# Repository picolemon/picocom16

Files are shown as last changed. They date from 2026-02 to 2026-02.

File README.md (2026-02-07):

# Picocom16
A DIY breadboard computer based on four RP2350 micro controllers that can be built without any soldering.

Markdown Logo

## Features
Easy build with no soldering.

Fast debugging using VSCode and a usb cable.

Double buffered frame buffer with simple gpu for drawing.

Async DMA bus distributes graphics and sound to each core.

Written in C with a clear and simple api.

## Display

Frame buffer: 320×224, 16 bit color palette, 60 Hz.    

GPU Method: Command dispatch and Tiling.

Blend modes:  4bit alpha composite, Additive blending.

## Memory

System RAM: 512 KB SRAM

VRAM: 512 KB SRAM

FB: 512 KB SRAM

Audio RAM: 512 KB SRAM

## DMA
VDP1 Bus - System to VDP gpu command stream async.

VDP2 Bus - VDP1 to VDP2 tile stream.

APU Bus - System to APU audio commands, audio streams, HID inputs and SD Card IO.

## Storage
Physics format: Format: SD memory card.

File System: Fat32.

## Audio
DSP mixer: play, pause, pan & frequency.

Audio formats: Raw PCM 16, OGG vorbis.

Streaming: Audio stream buffer for seamless audio looping and streaming from System core.

Rate: 11 Khz.

Output: Stereo output via 3mm jack.

Channels: 32 channels ( sfx or ogg in any combination ).

## Cores
APU - Dedicated audio processor. [ [src](sw/apu) ] [ [uf2](firmware/apu.uf2) ]

System - Game processor for game logic, building graphics and audio commands.  [ [demos](sw/demos) ] 

VDP1 - Graphics tile generator.  [ [src](sw/vdp1) ] [ [uf2](firmware/vdp1.uf2) ]

VDP2 - Tile compositor and DVI output.  [ [src](sw/vdp2) ] [ [uf2](firmware/vdp2.uf2) ]

## Examples

gfx_demo [ [src](sw/demos/gfx_demo) ] [ [uf2](firmware/gfx_demo.uf2) ]

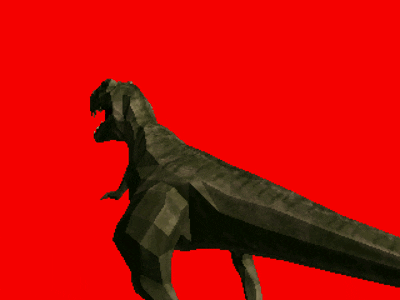
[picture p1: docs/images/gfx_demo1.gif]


input_demo  [ [src](sw/demos/gfx_demo) ] [ [uf2](firmware/gfx_demo.uf2) ]

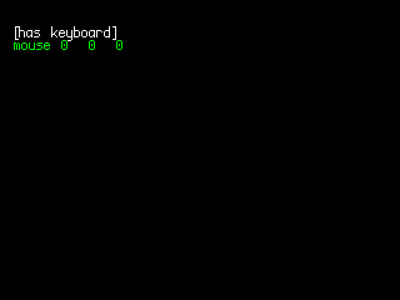
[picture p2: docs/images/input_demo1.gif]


minerload   [ [demo](https://picocom16.itch.io/minerload) ] [ [uf2](firmware/minerload.uf2) ]



## Components BOM

All components can be source from amazon or other suppliers.

    1 x Breadboard kit - SUNFOUNDER 5PCS Breadboards Kit Include 3PCS 830 Point 2PCS 400 Point Solderless Breadboard Compatible with Arduino Proto Shield Distribution Connecting Blocks 

    1 x Wire kit - 560 Pcs Jumper Wire Kit, 14 Lengths Assorted Preformed Breadboard Jumper Wires, Male to Male Solderless Jumper Cables with Storage Box for Prototyping, LED Strips, and Test Circuits 

    4 x Pre-Soldered Raspberry Pi Pico 2 with Header RP2350 Microcontroller Board Mini Board Kit Based on RP2350 Chip,Dual-core & Dual-architecture,Support C/C++/Python 

    1 x PCM5102 DAC Decoder Module I2S Interface GY-PCM5102 PHAT Format Player Board Digital-to-Analog Converter Voice Module for Arduino, Raspberry Pi with 3.5mm Jack Audio Cable, Dupont Cable 

    1 x AZDelivery Micro SD SPI Storage Board TF Memory Card Adapter Shield Module 5V compatible with Arduino Including E-Book! (Pack of 3) 

    1 x Adafruit DVI Breakout Board - For HDMI Source Devices 

    1 x 18pcs USB to DIP Breakout Adapter Converter Mini 5p USB/2.54 mm 4p/USB 2.0 4p/USB 3.0 Flat/Micro USB Type B/USB Type-B Square PCB Power Breakout Board Module

## Build guide
This is what the fully assembled breadboard looks like:

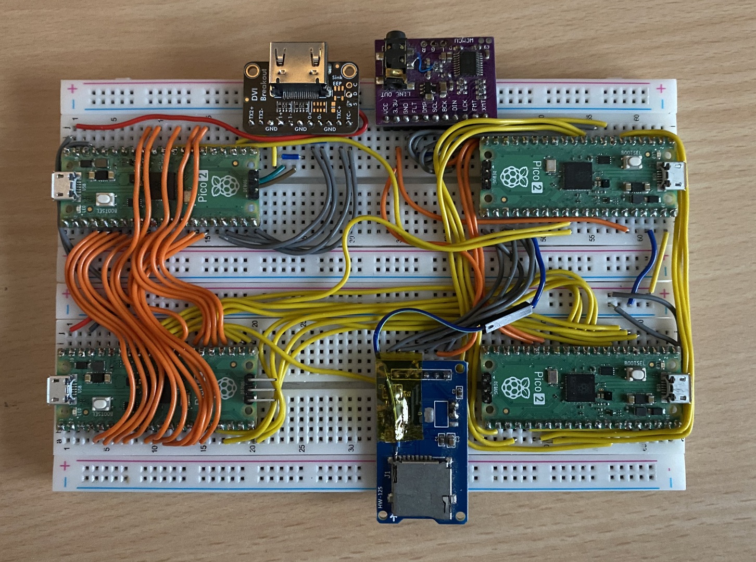
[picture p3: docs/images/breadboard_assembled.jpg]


See [docs/guides/picocom16-breadboard/Build-guide.md](docs/guides/picocom16-breadboard/Build-guide.md)

## System dependencies

VSCode: https://code.visualstudio.com/

Pico sdk: https://marketplace.visualstudio.com/items?itemName=raspberry-pi.raspberry-pi-pico

Asset tooling python deps
```
pip install bdfparser
```

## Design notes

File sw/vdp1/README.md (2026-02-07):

# VDP1
Video processor for rendering graphics

## Features
- connects to VDP2 via vdpbus 8bit wide write only bus
- sends frame and commands to VDP2 for compositing with frame buffer

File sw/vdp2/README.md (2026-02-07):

# VDP2
Background video processor and framebuffer for rendering graphics

## Features
- DVI video transmitter 
- Composites VDP1 scanlines into frame buffer
- Renders backgrounds ( and other effects ) just in time for VDP1 scanlines.
- post effects can be performed etc even using the prev frame ( currently output to dvi )

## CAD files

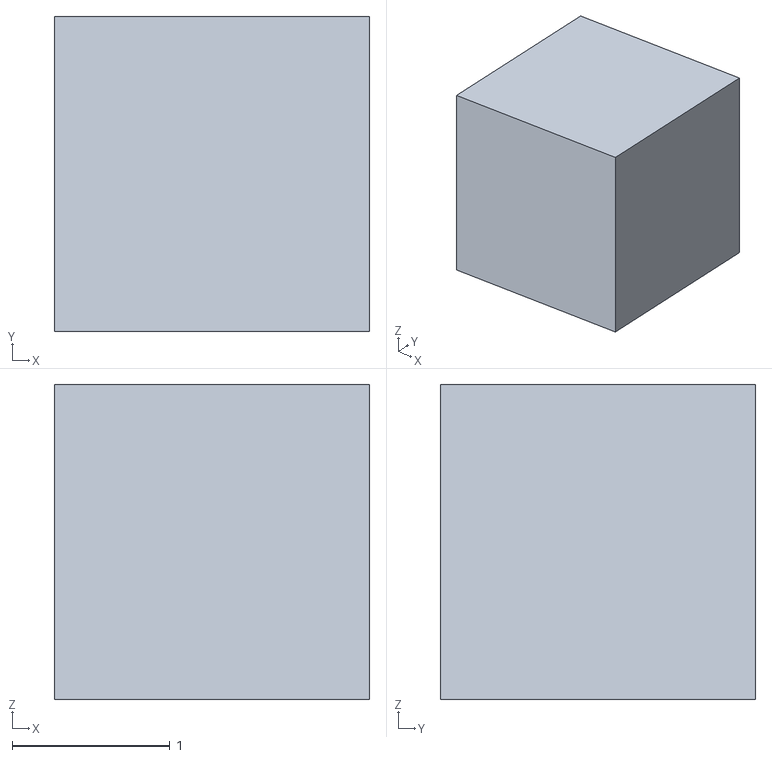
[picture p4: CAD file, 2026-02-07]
sw/demos/gfx_demo/assets/models/cube.obj
2.00 x 2.00 x 2.00

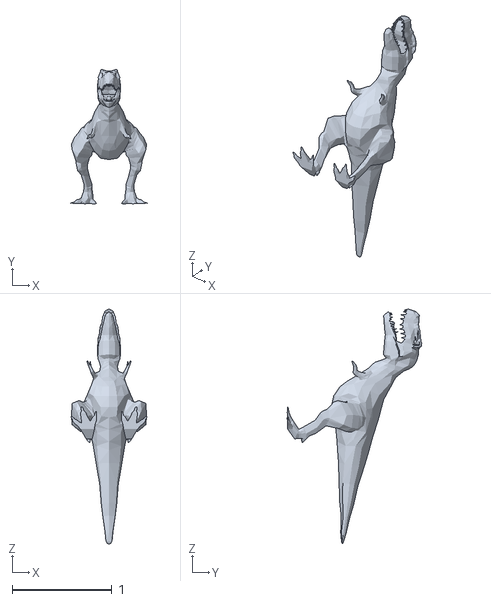
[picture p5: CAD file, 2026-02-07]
sw/demos/gfx_demo/assets/models/trex/T_Rex_1_FBX_LOW.fbx.obj
0.763 x 1.35 x 2.35

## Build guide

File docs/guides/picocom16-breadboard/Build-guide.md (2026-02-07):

# Picocom16 Breadboard build guide

## Intro
The picocom 16 breadboard console is an easy to build fully featured computer.

## BOM
    1 x Breadboard kit - SUNFOUNDER 5PCS Breadboards Kit Include 3PCS 830 Point 2PCS 400 Point Solderless Breadboard Compatible with Arduino Proto Shield Distribution Connecting Blocks 

    1 x Wire kit - 560 Pcs Jumper Wire Kit, 14 Lengths Assorted Preformed Breadboard Jumper Wires, Male to Male Solderless Jumper Cables with Storage Box for Prototyping, LED Strips, and Test Circuits 

    4 x Pre-Soldered Raspberry Pi Pico 2 with Header RP2350 Microcontroller Board Mini Board Kit Based on RP2350 Chip,Dual-core & Dual-architecture,Support C/C++/Python 

    1 x PCM5102 DAC Decoder Module I2S Interface GY-PCM5102 PHAT Format Player Board Digital-to-Analog Converter Voice Module for Arduino, Raspberry Pi with 3.5mm Jack Audio Cable, Dupont Cable 

    1 x AZDelivery Micro SD SPI Storage Board TF Memory Card Adapter Shield Module 5V compatible with Arduino Including E-Book! (Pack of 3) 

    1 x Adafruit DVI Breakout Board - For HDMI Source Devices 

    1 x 18pcs USB to DIP Breakout Adapter Converter Mini 5p USB/2.54 mm 4p/USB 2.0 4p/USB 3.0 Flat/Micro USB Type B/USB Type-B Square PCB Power Breakout Board Module

## Workflow
Copy the wiring diagrams in each section or open the Kicad project and following the wires from the schematic or pcb view.

At keys stages UF2 images are provided to test for certain features eg. does the audio output. To flash these images to specific chips plug a usb cable while holding the bootsel button then copy the image onto the RP2350 drive mount.

## Step 1 - HDMI
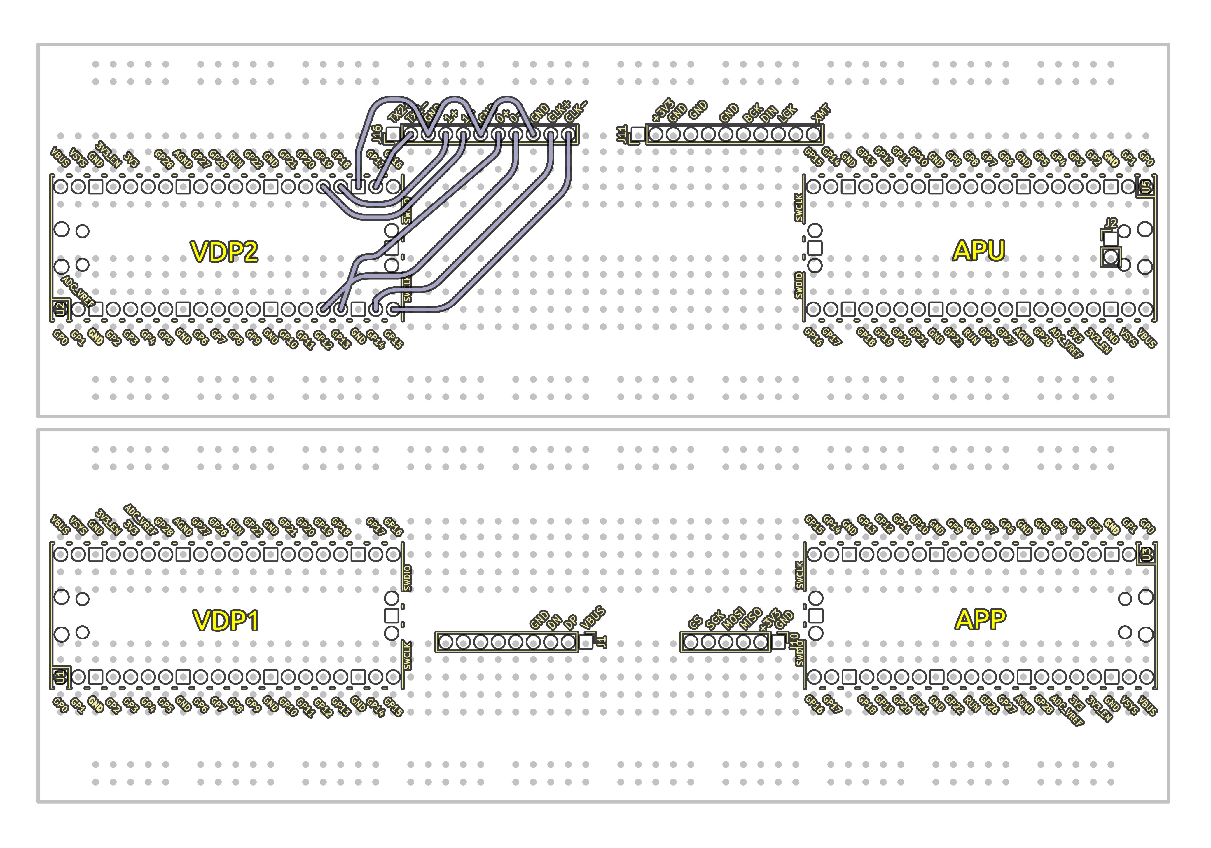
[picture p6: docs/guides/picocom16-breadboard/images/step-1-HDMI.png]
Breadboard

- Complete wiring diagram.
- Flash /firmware/vdp2.uf2 to the "VDP2" chip.
- The screen should go blue then after a few seconds a Red, Green, Blue vertical strip pattern should appear. If some colors are missing or the wrong order then double check the wiring. If no signal is detected then the display might not be compatible, some TV's require the 5V supply to be attached which requires soldering which is outside the scope of this guide.

## Step 2 - DAC
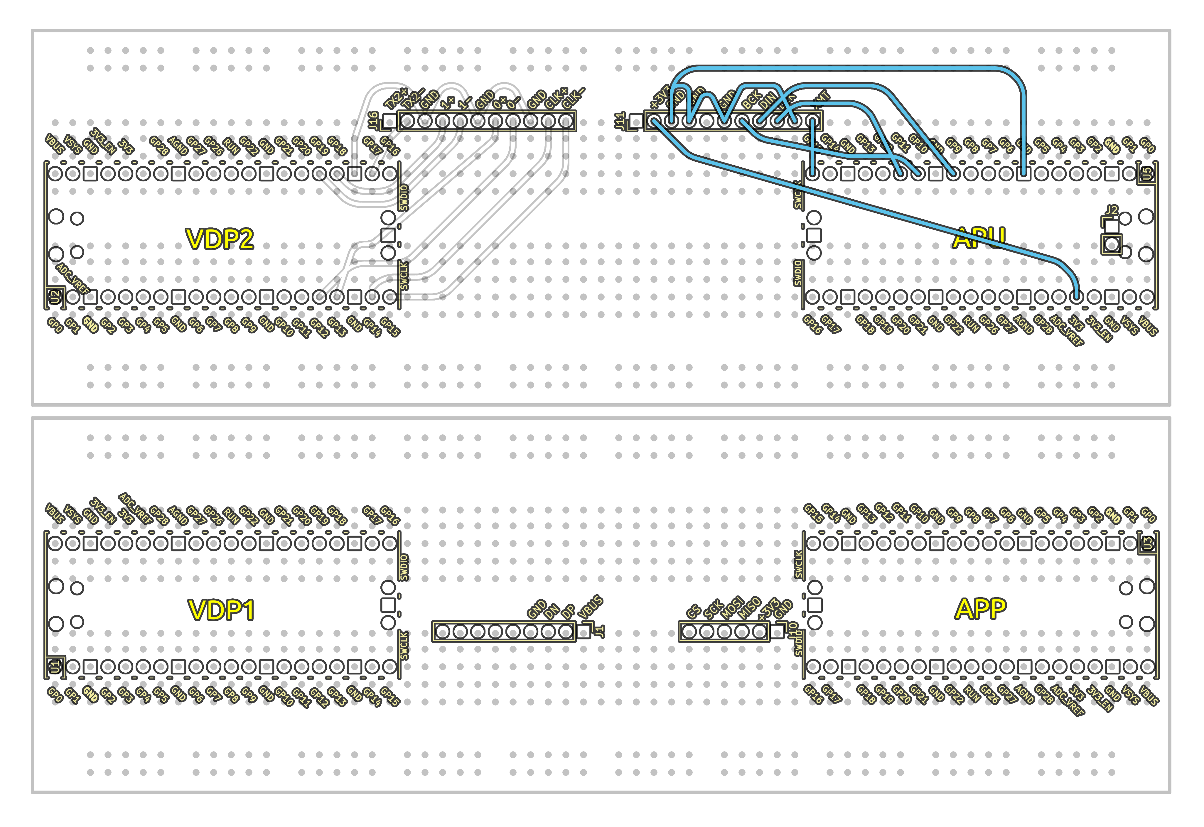
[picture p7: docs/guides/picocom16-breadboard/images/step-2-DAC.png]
Breadboard

- Follow the DAC wiring diagram. 
- Flash /firmware/vdp2.uf2 to the "APU" chip.
- Plug a set of headphones or speakers into the mini jack port on the DAC module.
- After 2 seconds a chime should be heard, if nothing plays then check the wiring.

## Step 3 - PWR
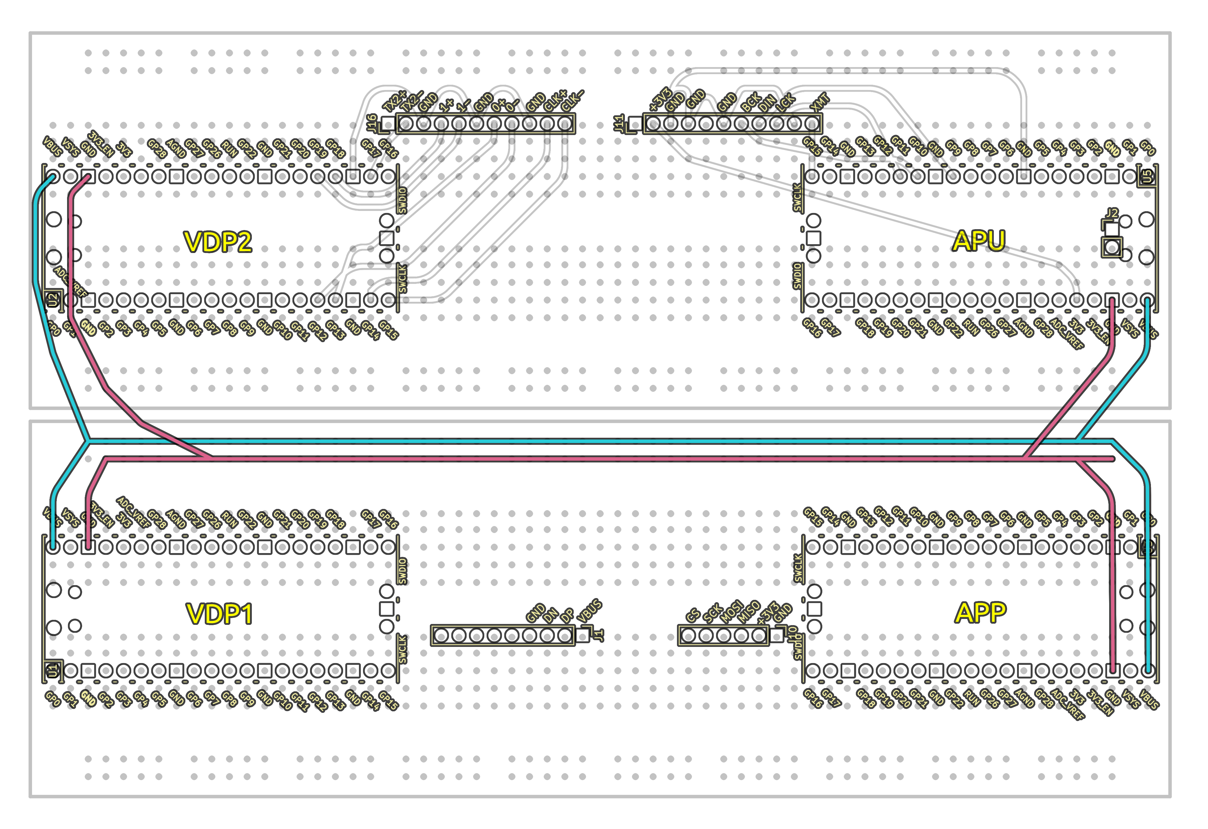
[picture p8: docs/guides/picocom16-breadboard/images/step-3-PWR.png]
Breadboard

- Follow the power wiring diagram. 

Note: Once wired, all pico the boards will startup. If you have multiple USB cables connected (an isolated usb is recommended for this) the bootsel will not work until all cables have been disconnected

## Step 4 - VLNK
- Follow the VLNK wiring diagram. 

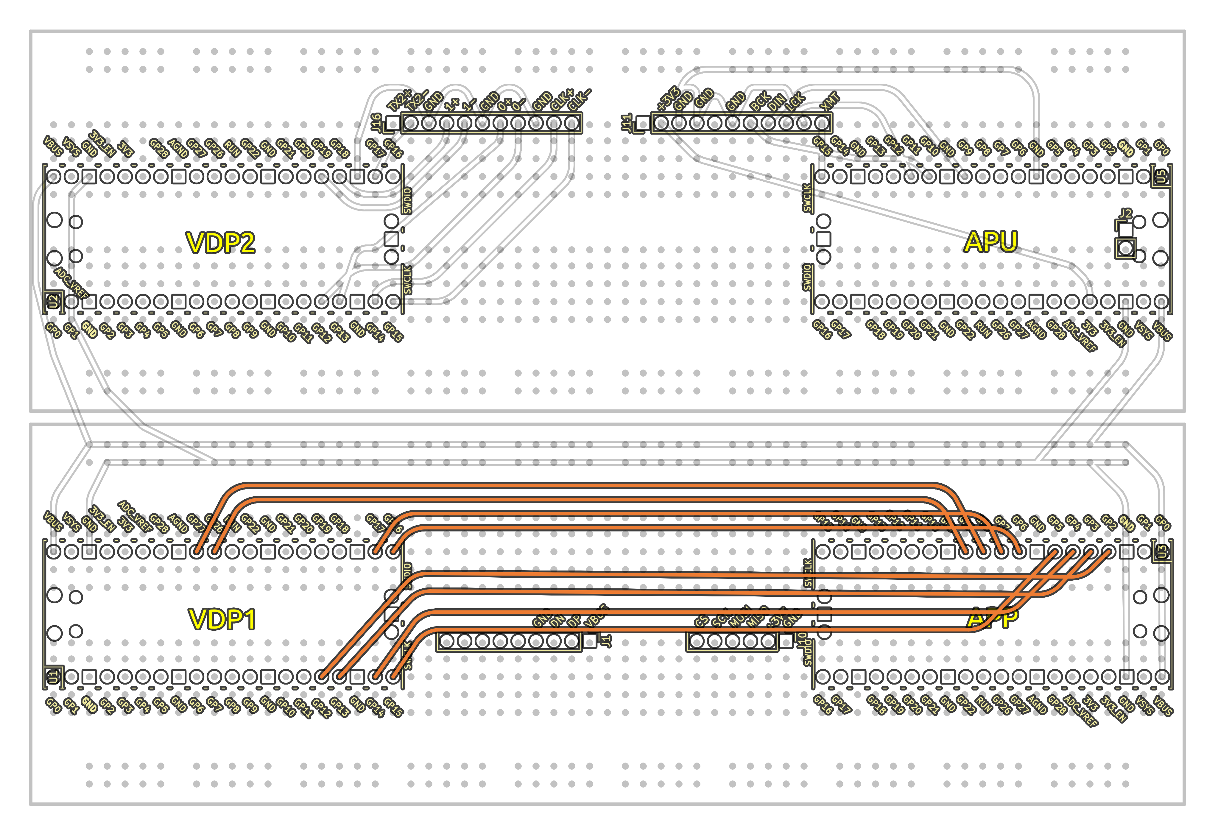
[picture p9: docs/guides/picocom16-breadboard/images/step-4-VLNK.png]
Breadboard

To validate the VLNK bus is wired correctly do the following steps to flash a temporary test firmware:
- Disconnect all usb / power cables and connect a single USB cable to the target board when flashing.
- Flash "step-4-VLNK/bustester_a.uf2" onto APP pico.
- Flash "step-4-VLNK/bustester_b.uf2" onto VDP1 pico.
- LEDs on both devices should go solid after 5.
- If no LEDs light up then attach a usb cable and connect to the vdp1 and/or app pico serial port (via putty or picocom ) see the diagnostic output eg.
```
[APP->VDP1 test] summary
        input[0] gpio: 5 holdSamples: 1248, state: 0, cycles: 2
        input[1] gpio: 6 holdSamples: 1248, state: 0, cycles: 2
        input[2] gpio: 7 holdSamples: 1248, state: 0, cycles: 0
```
for example input[2] appears to be disconnected, check the data-sheet and re-check the wiring to resolve.

## Step 5 - ALNK
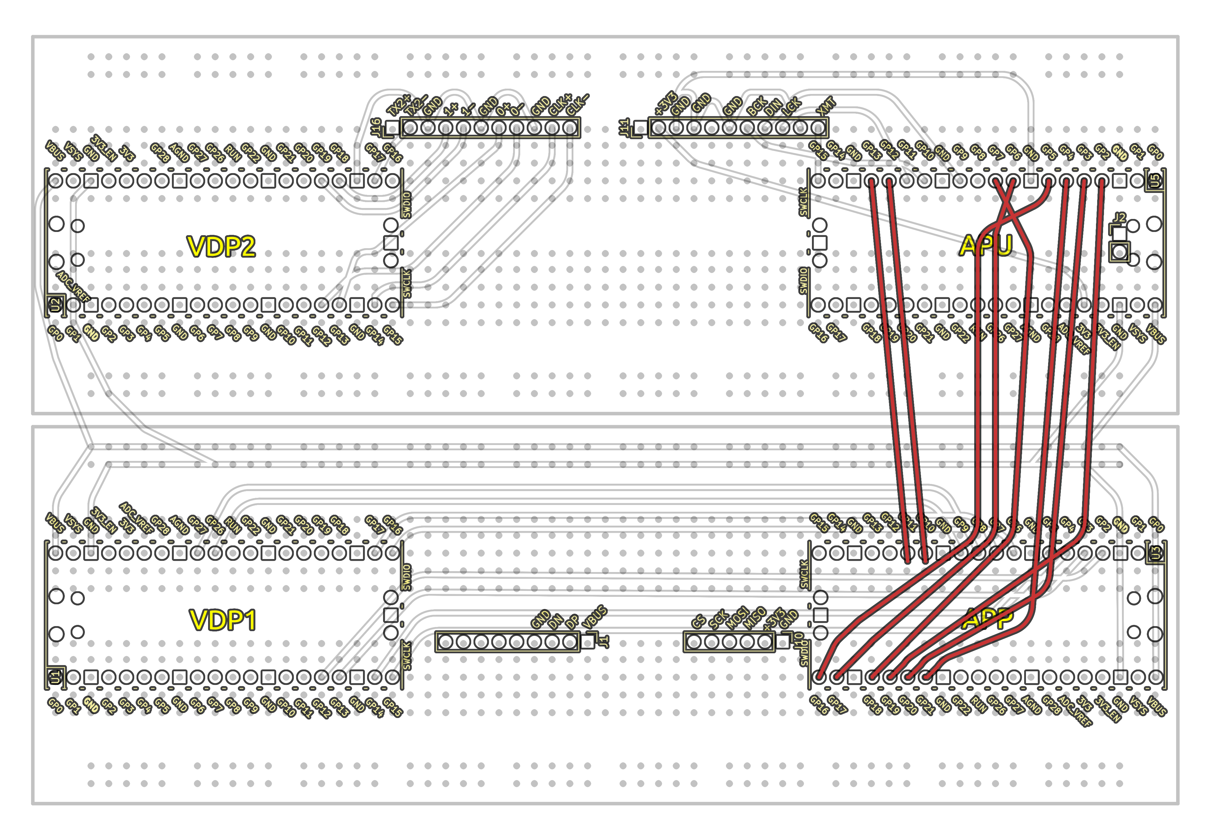
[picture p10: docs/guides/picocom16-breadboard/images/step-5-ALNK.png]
Breadboard

- Follow the ALNK wiring diagram. 
To validate the VLNK bus is wired correctly do the following steps to flash a temporary test firmware:

- Flash "Step-5-ALNK/bustester_a.uf2" onto APP pico.
- Flash "Step-5-ALNK/bustester_b.uf2" onto VDP1 pico.
- LEDs on both devices (APP and APU) should go solid after 5.
- Example output from the console on the APP device (if connected)
```
[APU->APP test] summary
        input[0] gpio: 2 holdSamples: 1, state: 1, cycles: 31
        input[1] gpio: 3 holdSamples: 19, state: 0, cycles: 30
        input[2] gpio: 4 holdSamples: 9, state: 0, cycles: 30
        txAckPin[ACK] gpio: 13 holdSamples: 1, state: 1, cycles: 46
```        

## Step 6 - SDCARD
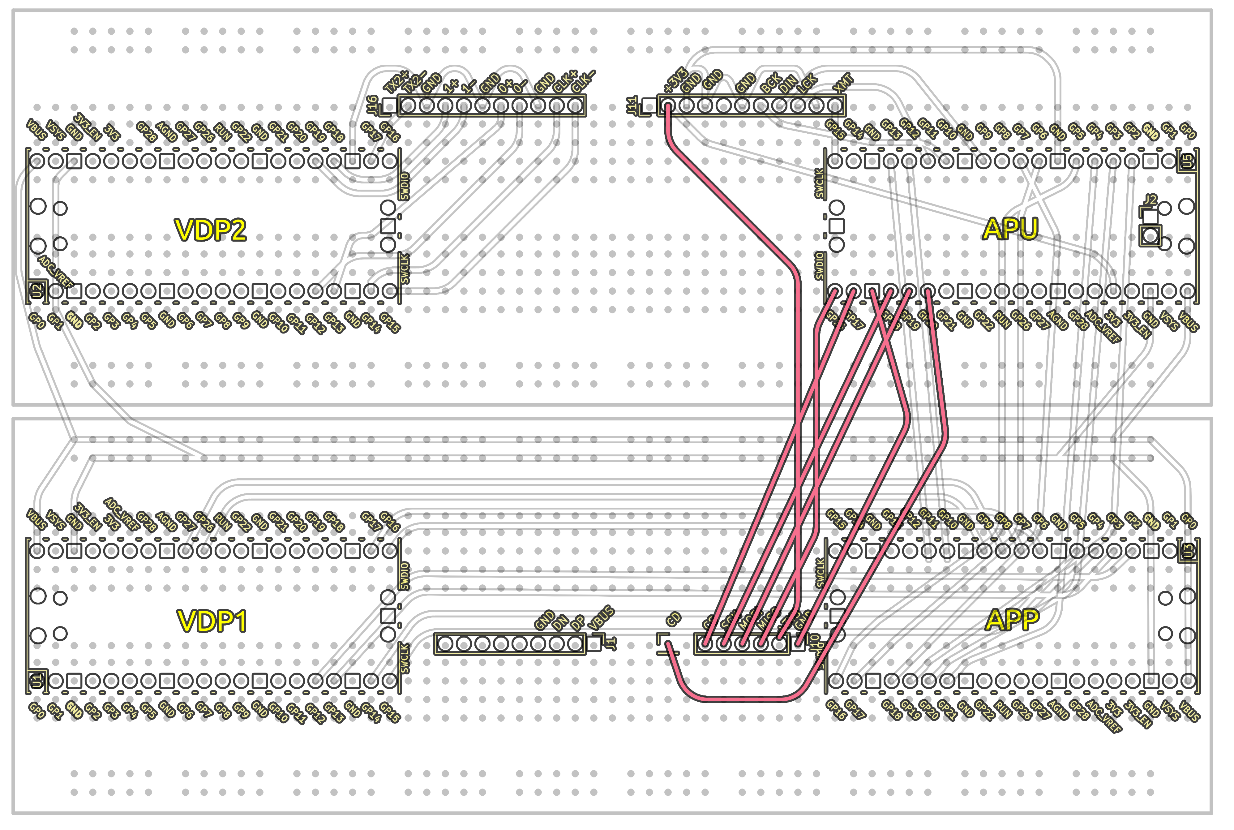
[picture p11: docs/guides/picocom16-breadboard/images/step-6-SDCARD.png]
Breadboard

- Follow the SDCARD wiring diagram. 

An extra wire was soldered to the SD Card module to bring out the card detect pin, some modules have this but may require soldering an extra wire. This can be disabled in the APU firmware ( sw/apu/src/hw_config.c ) if not used.

## Step 7 - FUSB (Optional)
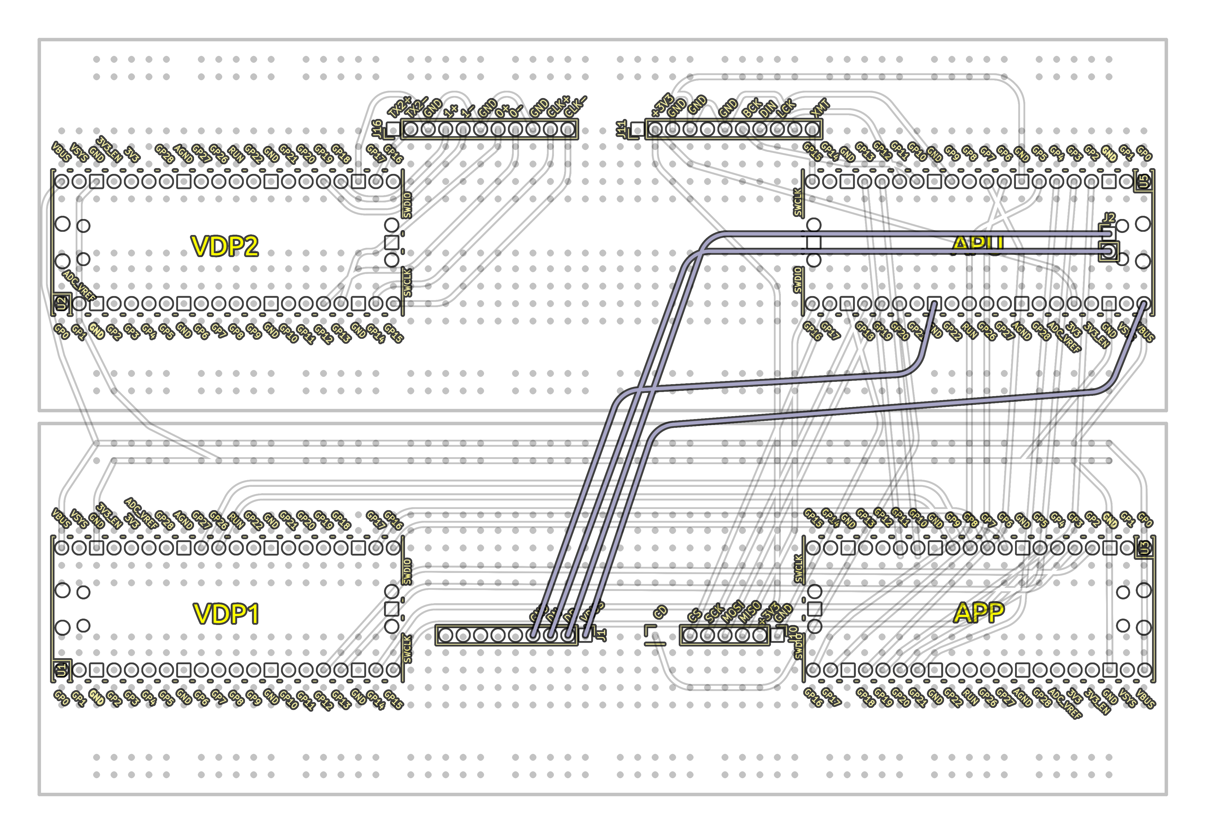
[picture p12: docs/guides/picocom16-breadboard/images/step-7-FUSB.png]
Breadboard

- Follow the FUSB wiring diagram. 
NOTE: A Micro USB OTG Hub Adapter can be plugged into the APU for USB functionality, this allows plugging in multiple devices instead of the limited FUSB port.

## Step 8 - RESET
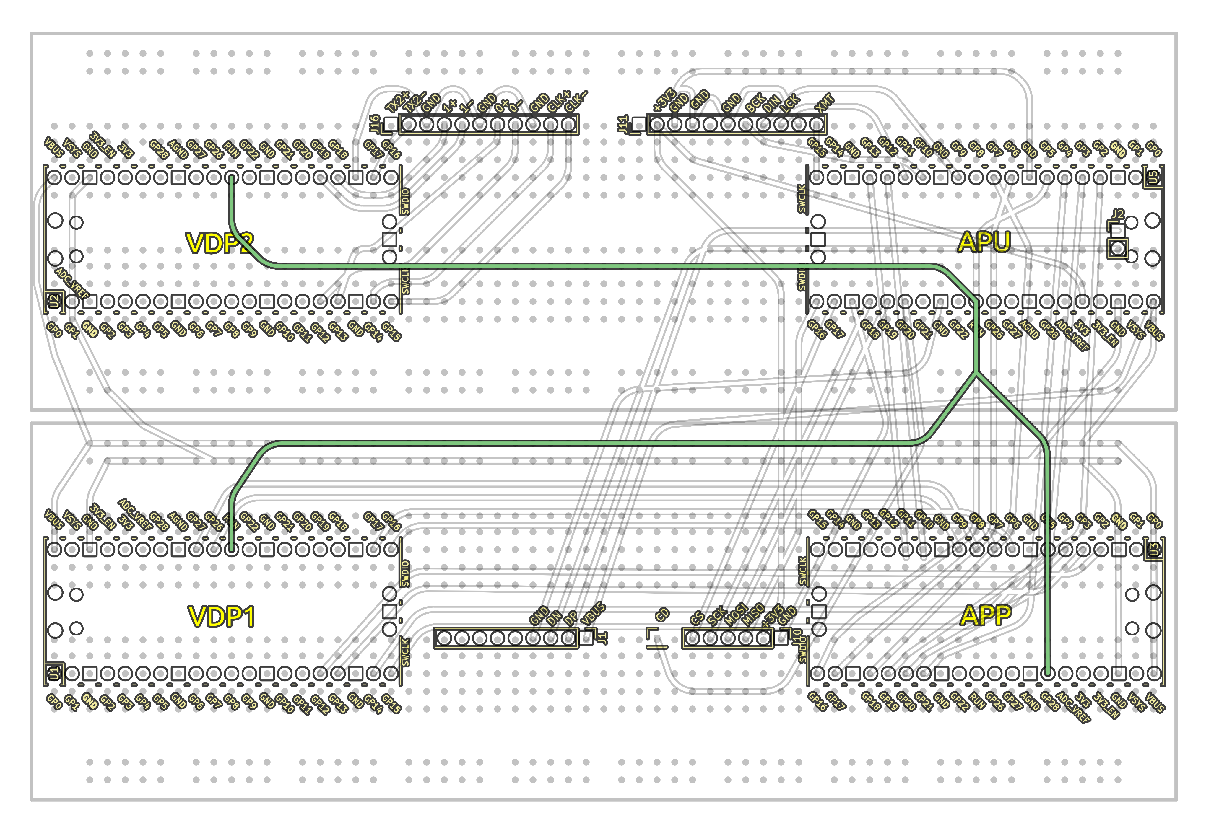
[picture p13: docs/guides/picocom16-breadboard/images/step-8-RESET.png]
Breadboard

- Follow the RESET wiring diagram. 

## Step 9 - VDBUS
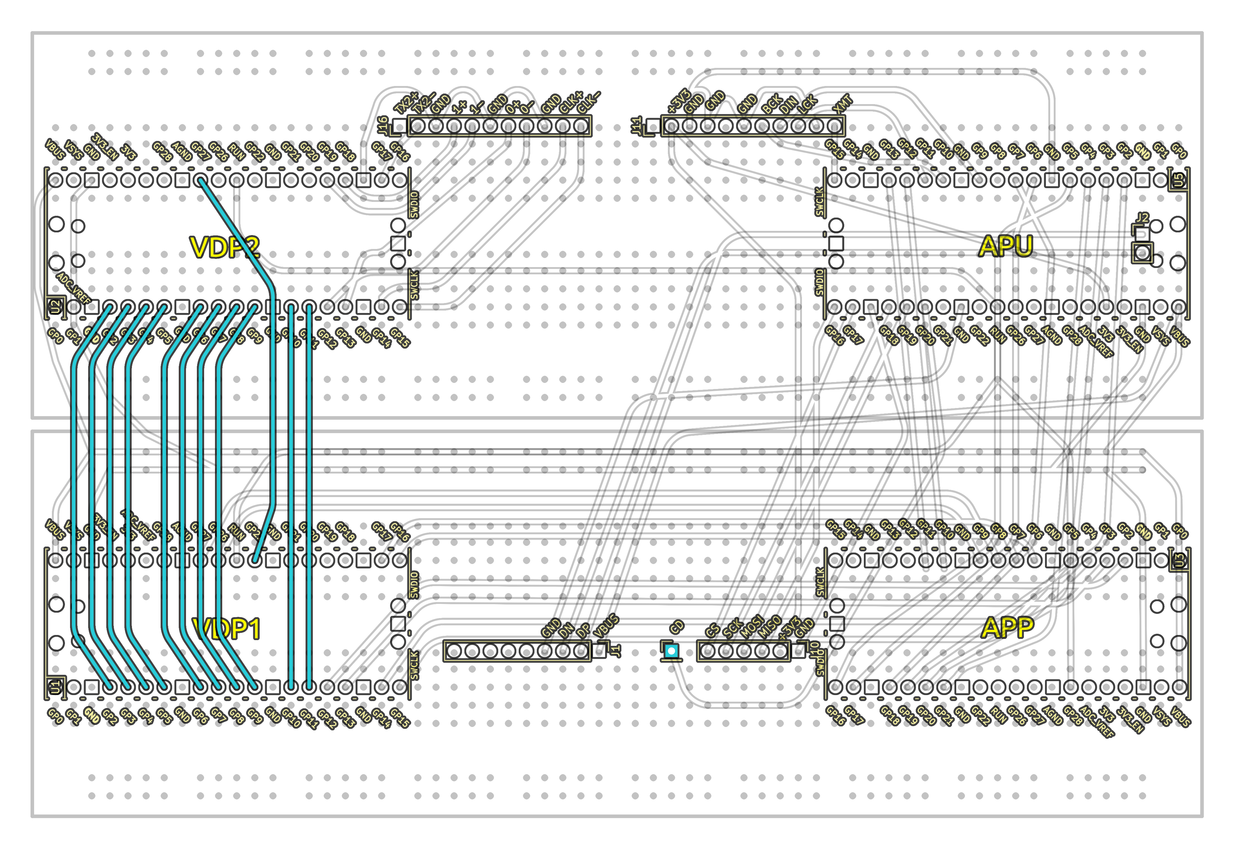
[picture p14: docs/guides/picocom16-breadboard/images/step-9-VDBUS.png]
Breadboard

- Follow the VDBUS wiring diagram. 

## Step 10 - XLNK
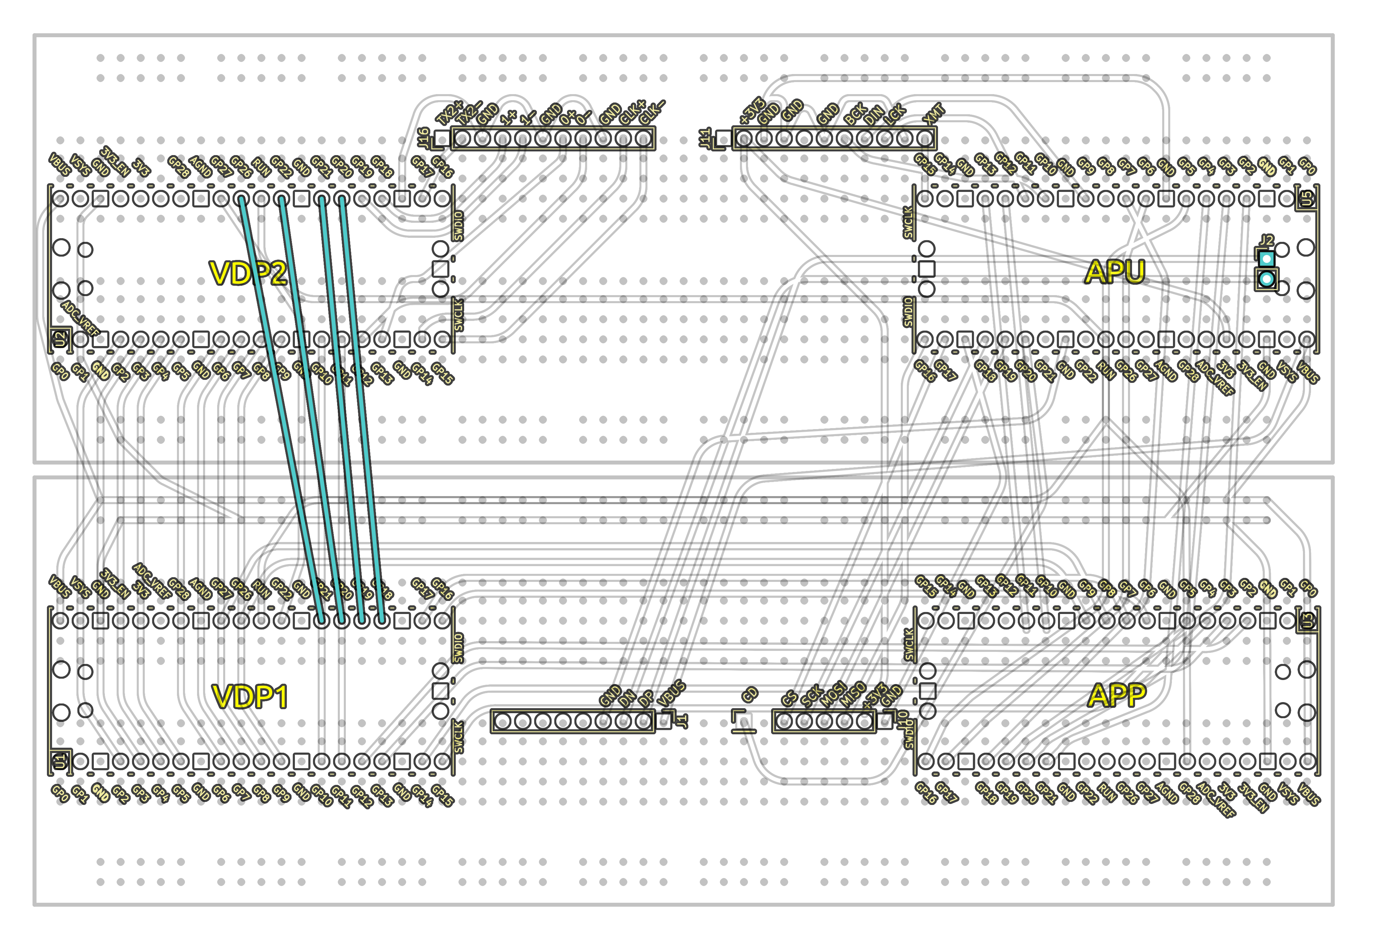
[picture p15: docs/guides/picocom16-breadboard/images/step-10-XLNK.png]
Breadboard

- Follow the XLNK wiring diagram. 

- Flash "Step-10-XLNK/bustester_a.uf2" onto VDP1 pico.
- Flash "Step-10-XLNK/bustester_b.uf2" onto VDP2 pico.
- LEDs on both devices (APP and APU) should go solid after 5.

## Step 11 - Display testing
Thats it, all components are wired and the wiring has been validated. To put the VDP through it paces an test program will send commands to VDP1 then to VDP2 to test the video output of the console.

- Flash "firmware/vdp2.uf2" onto the VDP2 pico.
- Flash "firmware/vdp1.uf2" onto the VDP1 pico.
- Flash "firmware/apu.uf2" onto the APU pico.
- Flash "firmware/gfx_demo.uf2" onto the APP pico.

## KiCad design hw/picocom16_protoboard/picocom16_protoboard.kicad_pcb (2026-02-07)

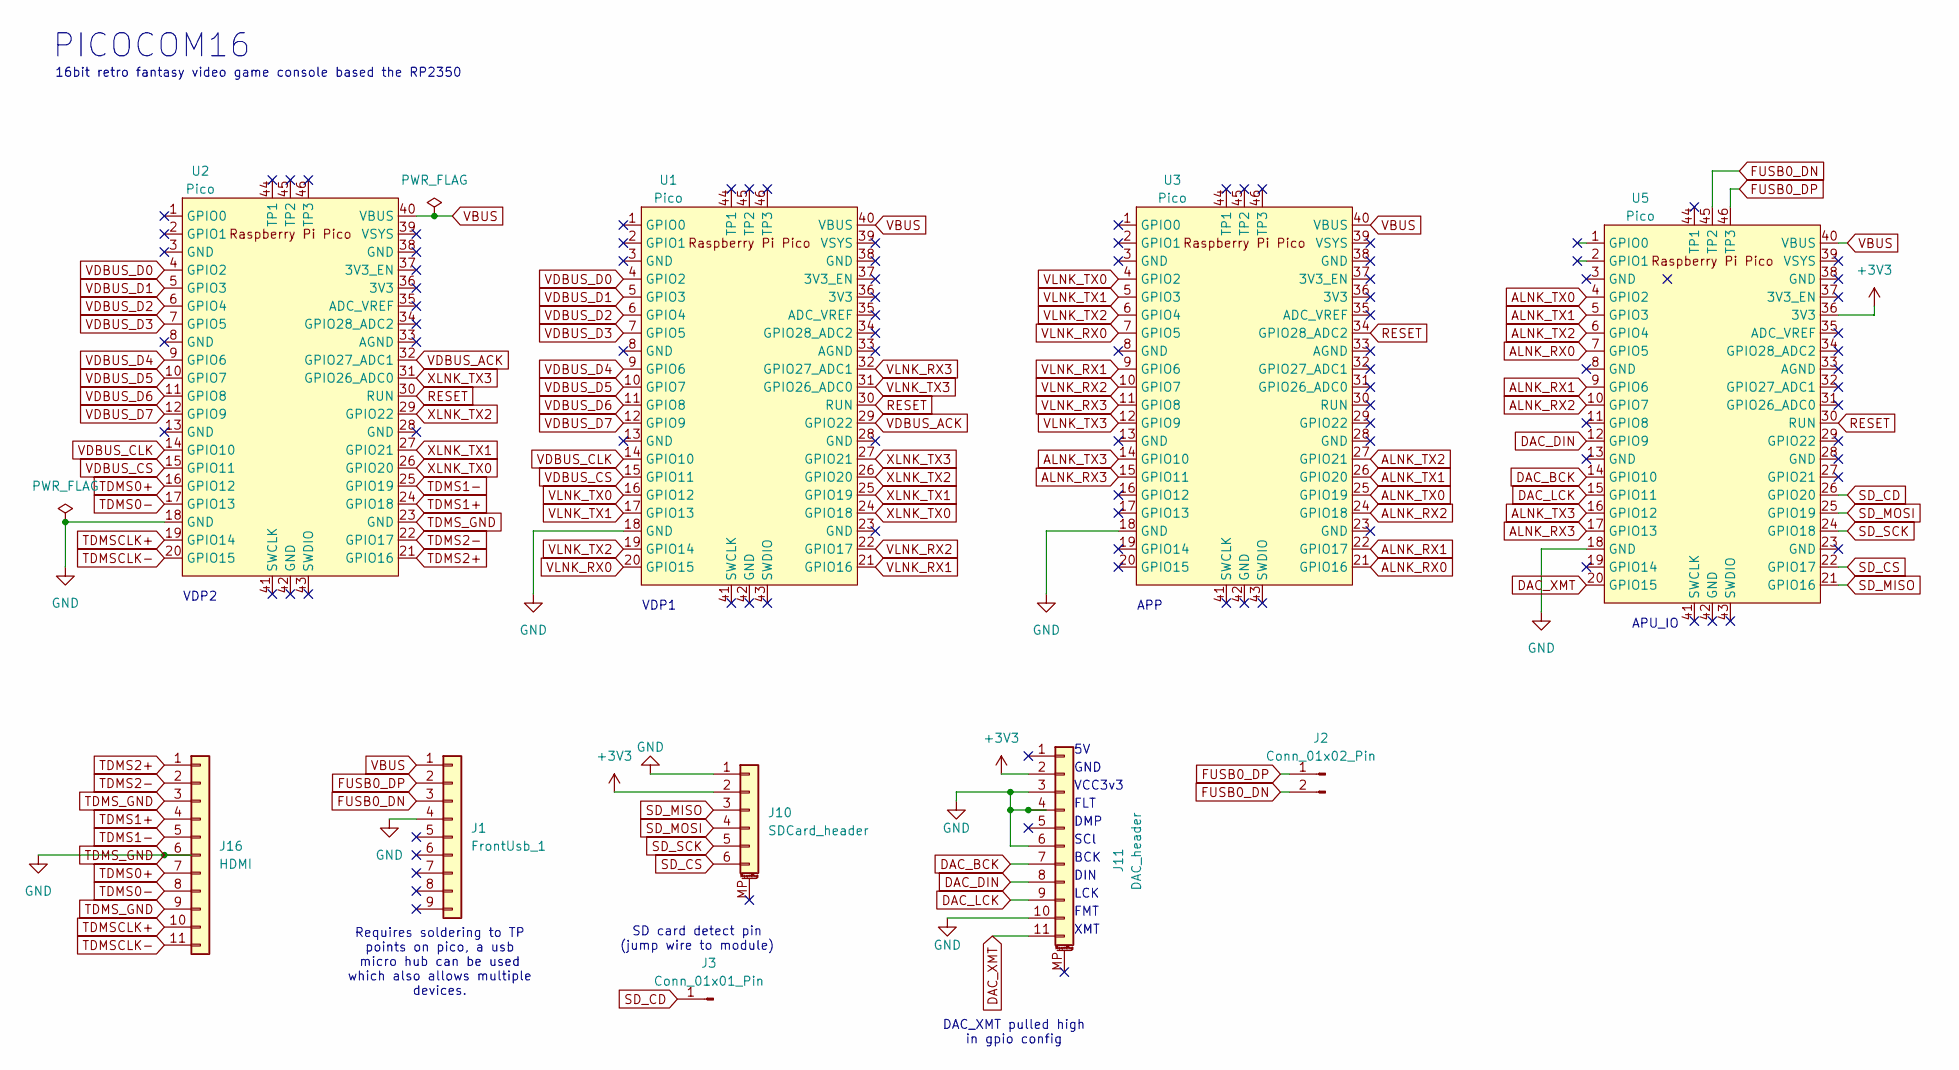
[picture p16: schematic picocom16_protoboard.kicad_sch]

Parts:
J1: FrontUsb_1; PinHeader_1x09_P2.54mm_Vertical
J2: Conn_01x02_Pin; PinHeader_1x02_P2.54mm_Vertical
J3: Conn_01x01_Pin; PinHeader_1x01_P2.54mm_Vertical
J10: SDCard_header; PinHeader_1x06_P2.54mm_Vertical
J11: DAC_header; PinHeader_1x11_P2.54mm_Vertical
J16: HDMI; PinHeader_1x11_P2.54mm_Vertical
U1, U2, U3, U5: Pico; RPi_Pico_SMD_TH

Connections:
+3V3: J10.2, J11.2, U5.36 (3V3)
ALNK_RX0: U3.21 (GPIO16), U5.7 (GPIO5)
ALNK_RX1: U3.22 (GPIO17), U5.9 (GPIO6)
ALNK_RX2: U3.24 (GPIO18), U5.10 (GPIO7)
ALNK_RX3: U3.15 (GPIO11), U5.17 (GPIO13)
ALNK_TX0: U3.25 (GPIO19), U5.4 (GPIO2)
ALNK_TX1: U3.26 (GPIO20), U5.5 (GPIO3)
ALNK_TX2: U3.27 (GPIO21), U5.6 (GPIO4)
ALNK_TX3: U3.14 (GPIO10), U5.16 (GPIO12)
DAC_BCK: J11.7, U5.14 (GPIO10)
DAC_DIN: J11.8, U5.12 (GPIO9)
DAC_LCK: J11.9, U5.15 (GPIO11)
DAC_XMT: J11.11, U5.20 (GPIO15)
FUSB0_DN: J1.3, J2.2, U5.45 (TP2)
FUSB0_DP: J1.2, J2.1, U5.46 (TP3)
RESET: U1.30 (RUN), U2.30 (RUN), U3.34 (GPIO28_ADC2), U5.30 (RUN)
SD_CD: J3.1, U5.26 (GPIO20)
SD_CS: J10.6, U5.22 (GPIO17)
SD_MISO: J10.3, U5.21 (GPIO16)
SD_MOSI: J10.4, U5.25 (GPIO19)
SD_SCK: J10.5, U5.24 (GPIO18)
TDMS0+: J16.7, U2.16 (GPIO12)
TDMS0-: J16.8, U2.17 (GPIO13)
TDMS1+: J16.4, U2.24 (GPIO18)
TDMS1-: J16.5, U2.25 (GPIO19)
TDMS2+: J16.1, U2.21 (GPIO16)
TDMS2-: J16.2, U2.22 (GPIO17)
TDMSCLK+: J16.10, U2.19 (GPIO14)
TDMSCLK-: J16.11, U2.20 (GPIO15)
TDMS_GND: J1.4, J10.1, J11.3, J11.4, J11.6, J11.10, J16.3, J16.6, J16.9, U1.18 (GND), U2.18 (GND), U2.23 (GND), U3.18 (GND), U5.18 (GND)
VBUS: J1.1, U1.40 (VBUS), U2.40 (VBUS), U3.40 (VBUS), U5.40 (VBUS)
VDBUS_ACK: U1.29 (GPIO22), U2.32 (GPIO27_ADC1)
VDBUS_CLK: U1.14 (GPIO10), U2.14 (GPIO10)
VDBUS_CS: U1.15 (GPIO11), U2.15 (GPIO11)
VDBUS_D0: U1.4 (GPIO2), U2.4 (GPIO2)
VDBUS_D1: U1.5 (GPIO3), U2.5 (GPIO3)
VDBUS_D2: U1.6 (GPIO4), U2.6 (GPIO4)
VDBUS_D3: U1.7 (GPIO5), U2.7 (GPIO5)
VDBUS_D4: U1.9 (GPIO6), U2.9 (GPIO6)
VDBUS_D5: U1.10 (GPIO7), U2.10 (GPIO7)
VDBUS_D6: U1.11 (GPIO8), U2.11 (GPIO8)
VDBUS_D7: U1.12 (GPIO9), U2.12 (GPIO9)
VLNK_RX0: U1.20 (GPIO15), U3.7 (GPIO5)
VLNK_RX1: U1.21 (GPIO16), U3.9 (GPIO6)
VLNK_RX2: U1.22 (GPIO17), U3.10 (GPIO7)
VLNK_RX3: U1.32 (GPIO27_ADC1), U3.11 (GPIO8)
VLNK_TX0: U1.16 (GPIO12), U3.4 (GPIO2)
VLNK_TX1: U1.17 (GPIO13), U3.5 (GPIO3)
VLNK_TX2: U1.19 (GPIO14), U3.6 (GPIO4)
VLNK_TX3: U1.31 (GPIO26_ADC0), U3.12 (GPIO9)
XLNK_TX0: U1.24 (GPIO18), U2.26 (GPIO20)
XLNK_TX1: U1.25 (GPIO19), U2.27 (GPIO21)
XLNK_TX2: U1.26 (GPIO20), U2.29 (GPIO22)
XLNK_TX3: U1.27 (GPIO21), U2.31 (GPIO26_ADC0)

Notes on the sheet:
APP
VDP1
VCC3v3
FMT
DMP
DIN
SD card detect pin (jump wire to module)
16bit retro fantasy video game console based the RP2350
XMT
VDP2
FLT
GND
SCl
DAC_XMT pulled high in gpio config
Requires soldering to TP points on pico, a usb micro hub can be used which also allows multiple devices.
PICOCOM16
APU_IO
LCK
BCK

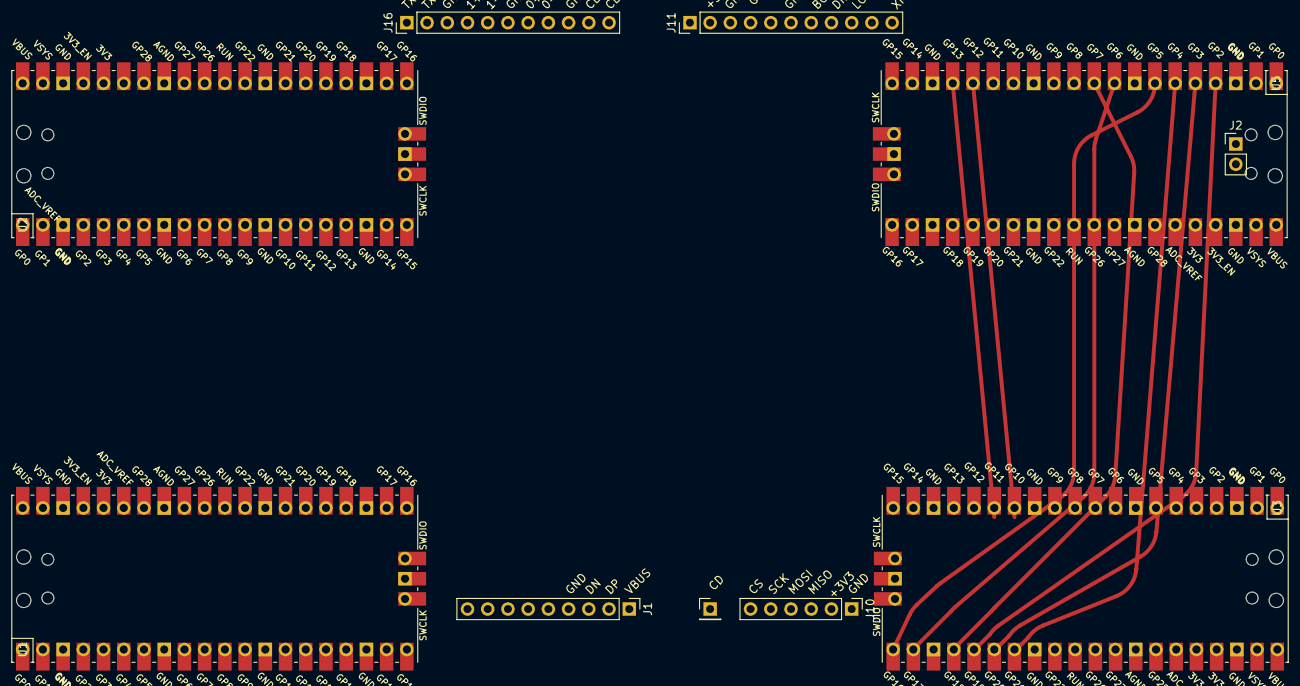
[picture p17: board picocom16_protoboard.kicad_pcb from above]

Board: 18 copper layers, 10 parts (0 on the bottom side), 54 nets.

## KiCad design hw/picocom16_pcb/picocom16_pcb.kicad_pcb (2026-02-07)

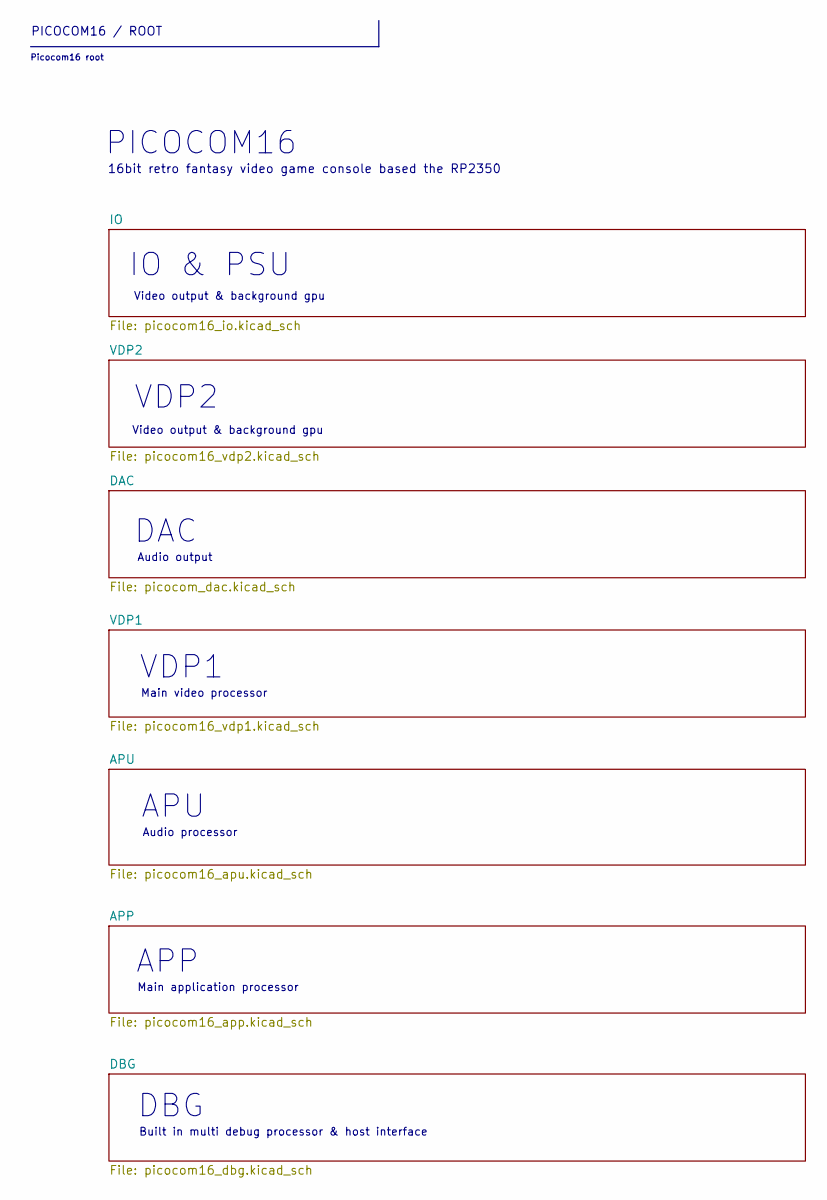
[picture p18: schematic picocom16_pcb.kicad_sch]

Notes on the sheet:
VDP2
Main application processor
Audio output
Built in multi debug processor & host interface
PICOCOM16 / ROOT
Video output & background gpu
VDP1
IO & PSU
16bit retro fantasy video game console based the RP2350
APP
Picocom16 root
Main video processor
DBG
APU
PICOCOM16
DAC
Audio processor

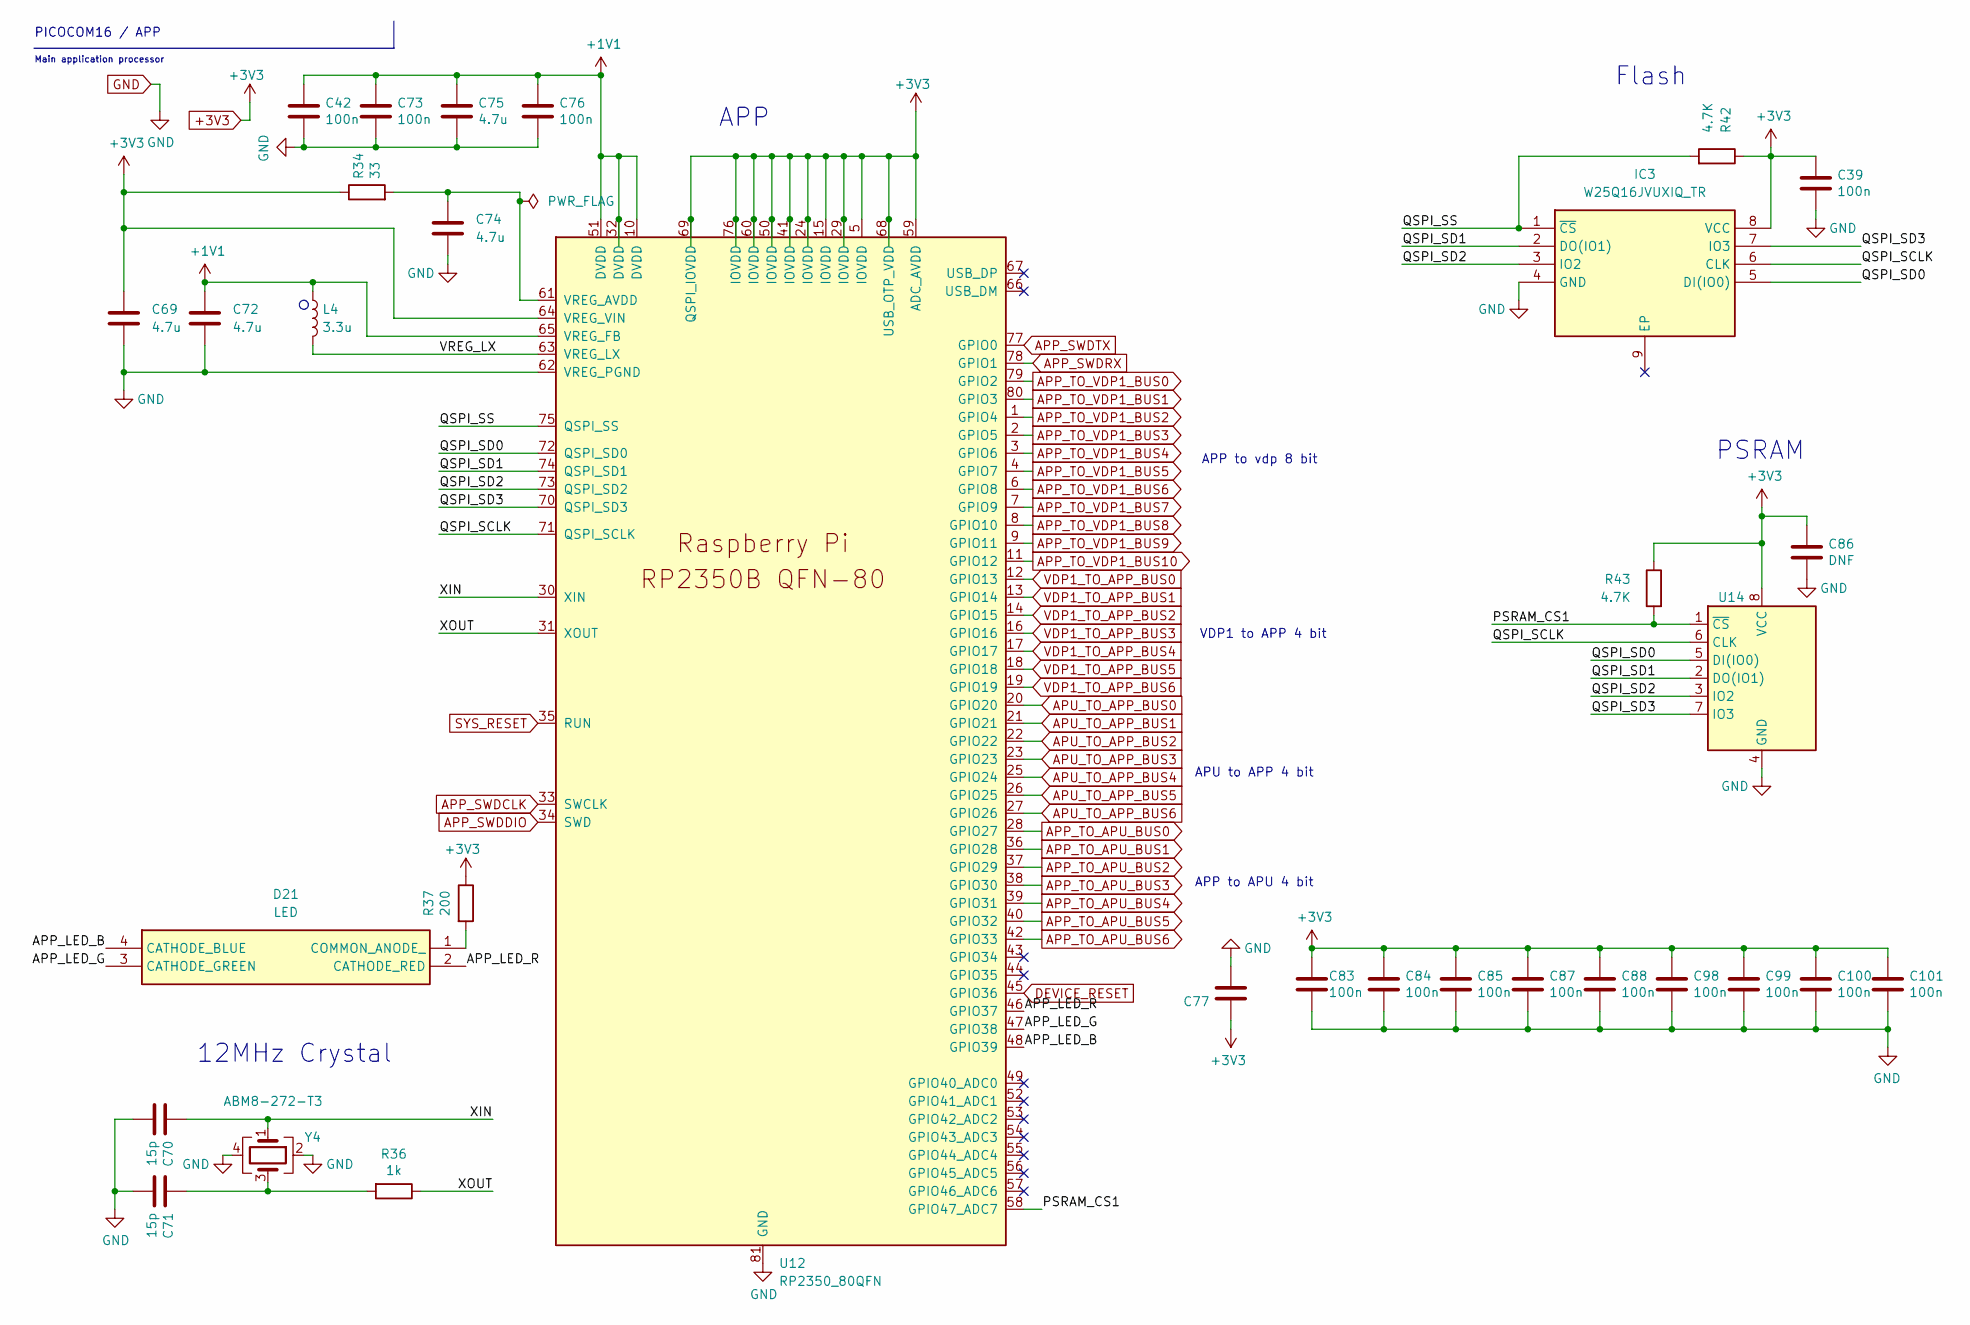
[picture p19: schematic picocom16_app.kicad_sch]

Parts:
C39, C42, C73, C76, C83, C84, C85, C87, C88, C98, C99, C100, C101: 100n; C_0402_1005Metric
C69, C72, C74, C75: 4.7u; C_0402_1005Metric
C70, C71: 15p; C_0402_1005Metric
C77: 10u; C_0805_2012Metric
C86: DNF; C_0402_1005Metric
D21: LRTBR48G-P9Q7-1+R7S5-26+NP-68; LRTBR48GP9Q71R7S526NP68; Mouser Part Number 720-LRTBR48GP9A3521
IC3: W25Q16JVUXIQ_TR; SON50P300X200X60-9N; Mouser Part Number 454-W25Q16JVUXIQTR
L4: 3.3u; L_0805_2012Metric
R34: 33; R_0402_1005Metric
R36: 1k; R_0402_1005Metric
R37: 200; R_0402_1005Metric
R42, R43: 4.7K; R_0402_1005Metric
U12: RP2350_80QFN; RP2350-QFN-80-1EP_10x10_P0.4mm_EP3.4x3.4mm_ThermalVias
U14: SOIC-8_5.23x5.23mm_P1.27mm
Y4: ABM8-272-T3; ABM8272T3

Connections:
+1V1: C42.1, C72.1, C73.1, C75.1, C76.1, L4.1, U12.10 (DVDD), U12.32 (DVDD), U12.51 (DVDD), U12.65 (VREG_FB); also elsewhere on the board
+3V3: C39.1, C69.1, C77.1, C83.1, C84.1, C85.1, C86.1, C87.1, C88.1, C98.1, C99.1, C100.1, C101.1, IC3.8 (VCC), R34.1, R37.1, R42.1, R43.1, U12.5 (IOVDD), U12.15 (IOVDD), U12.24 (IOVDD), U12.29 (IOVDD), U12.41 (IOVDD), U12.50 (IOVDD), U12.59 (ADC_AVDD), U12.60 (IOVDD), U12.64 (VREG_VIN), U12.68 (USB_OTP_VDD), U12.69 (QSPI_IOVDD), U12.76 (IOVDD), U14.8 (VCC); also elsewhere on the board
/APP/APP_LED_B: D21.4 (CATHODE_BLUE), U12.48 (GPIO39)
/APP/APP_LED_G: D21.3 (CATHODE_GREEN), U12.47 (GPIO38)
/APP/APP_LED_R: D21.2 (CATHODE_RED), U12.46 (GPIO37)
/APP/PSRAM_CS1: R43.2, U12.58 (GPIO47_ADC7), U14.1 (~CS)
/APP/QSPI_SCLK: IC3.6 (CLK), U12.71 (QSPI_SCLK), U14.6 (CLK)
/APP/QSPI_SD0: IC3.5 (DI(IO0)), U12.72 (QSPI_SD0), U14.5 (DI(IO0))
/APP/QSPI_SD1: IC3.2 (DO(IO1)), U12.74 (QSPI_SD1), U14.2 (DO(IO1))
/APP/QSPI_SD2: IC3.3 (IO2), U12.73 (QSPI_SD2), U14.3 (IO2)
/APP/QSPI_SD3: IC3.7 (IO3), U12.70 (QSPI_SD3), U14.7 (IO3)
/APP/QSPI_SS: IC3.1 (~CS), R42.2, U12.75 (QSPI_SS)
/APP/VREG_LX: L4.2, U12.63 (VREG_LX)
/APP/XIN: C70.1, U12.30 (XIN), Y4.1
/APP/XOUT: R36.1, U12.31 (XOUT)
APP_SWDCLK: U12.33 (SWCLK); also elsewhere on the board
APP_SWDDIO: U12.34 (SWD); also elsewhere on the board
APP_SWDRX: U12.78 (GPIO1); also elsewhere on the board
APP_SWDTX: U12.77 (GPIO0); also elsewhere on the board
APP_TO_APU_BUS0: U12.28 (GPIO27); also elsewhere on the board
APP_TO_APU_BUS1: U12.36 (GPIO28); also elsewhere on the board
APP_TO_APU_BUS2: U12.37 (GPIO29); also elsewhere on the board
APP_TO_APU_BUS3: U12.38 (GPIO30); also elsewhere on the board
APP_TO_APU_BUS4: U12.39 (GPIO31); also elsewhere on the board
APP_TO_APU_BUS5: U12.40 (GPIO32); also elsewhere on the board
APP_TO_APU_BUS6: U12.42 (GPIO33); also elsewhere on the board
APP_TO_VDP1_BUS0: U12.79 (GPIO2); also elsewhere on the board
APP_TO_VDP1_BUS1: U12.80 (GPIO3); also elsewhere on the board
APP_TO_VDP1_BUS2: U12.1 (GPIO4); also elsewhere on the board
APP_TO_VDP1_BUS3: U12.2 (GPIO5); also elsewhere on the board
APP_TO_VDP1_BUS4: U12.3 (GPIO6); also elsewhere on the board
APP_TO_VDP1_BUS5: U12.4 (GPIO7); also elsewhere on the board
APP_TO_VDP1_BUS6: U12.6 (GPIO8); also elsewhere on the board
APP_TO_VDP1_BUS7: U12.7 (GPIO9); also elsewhere on the board
APP_TO_VDP1_BUS8: U12.8 (GPIO10); also elsewhere on the board
APP_TO_VDP1_BUS9: U12.9 (GPIO11); also elsewhere on the board
APP_TO_VDP1_BUS10: U12.11 (GPIO12); also elsewhere on the board
APU_TO_APP_BUS0: U12.20 (GPIO20); also elsewhere on the board
APU_TO_APP_BUS1: U12.21 (GPIO21); also elsewhere on the board
APU_TO_APP_BUS2: U12.22 (GPIO22); also elsewhere on the board
APU_TO_APP_BUS3: U12.23 (GPIO23); also elsewhere on the board
APU_TO_APP_BUS4: U12.25 (GPIO24); also elsewhere on the board
APU_TO_APP_BUS5: U12.26 (GPIO25); also elsewhere on the board
APU_TO_APP_BUS6: U12.27 (GPIO26); also elsewhere on the board
DEVICE_RESET: U12.45 (GPIO36); also elsewhere on the board
GND: C39.2, C42.2, C69.2, C70.2, C71.2, C72.2, C73.2, C74.2, C75.2, C76.2, C77.2, C83.2, C84.2, C85.2, C86.2, C87.2, C88.2, C98.2, C99.2, C100.2, C101.2, IC3.4 (GND), U12.62 (VREG_PGND), U12.81 (GND), U14.4 (GND), Y4.2, Y4.4; also elsewhere on the board
unnamed: C71.1, R36.2, Y4.3
unnamed: D21.1 (COMMON_ANODE_), R37.2
unnamed: C74.1, R34.2, U12.61 (VREG_AVDD)
SYS_RESET: U12.35 (RUN); also elsewhere on the board
VDP1_TO_APP_BUS0: U12.12 (GPIO13); also elsewhere on the board
VDP1_TO_APP_BUS1: U12.13 (GPIO14); also elsewhere on the board
VDP1_TO_APP_BUS2: U12.14 (GPIO15); also elsewhere on the board
VDP1_TO_APP_BUS3: U12.16 (GPIO16); also elsewhere on the board
VDP1_TO_APP_BUS4: U12.17 (GPIO17); also elsewhere on the board
VDP1_TO_APP_BUS5: U12.18 (GPIO18); also elsewhere on the board
VDP1_TO_APP_BUS6: U12.19 (GPIO19); also elsewhere on the board

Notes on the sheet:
PSRAM
APP to APU 4 bit
APP to vdp 8 bit
APP
APU to APP 4 bit
12MHz Crystal
PICOCOM16 / APP
Main application processor
VDP1 to APP 4 bit
Flash

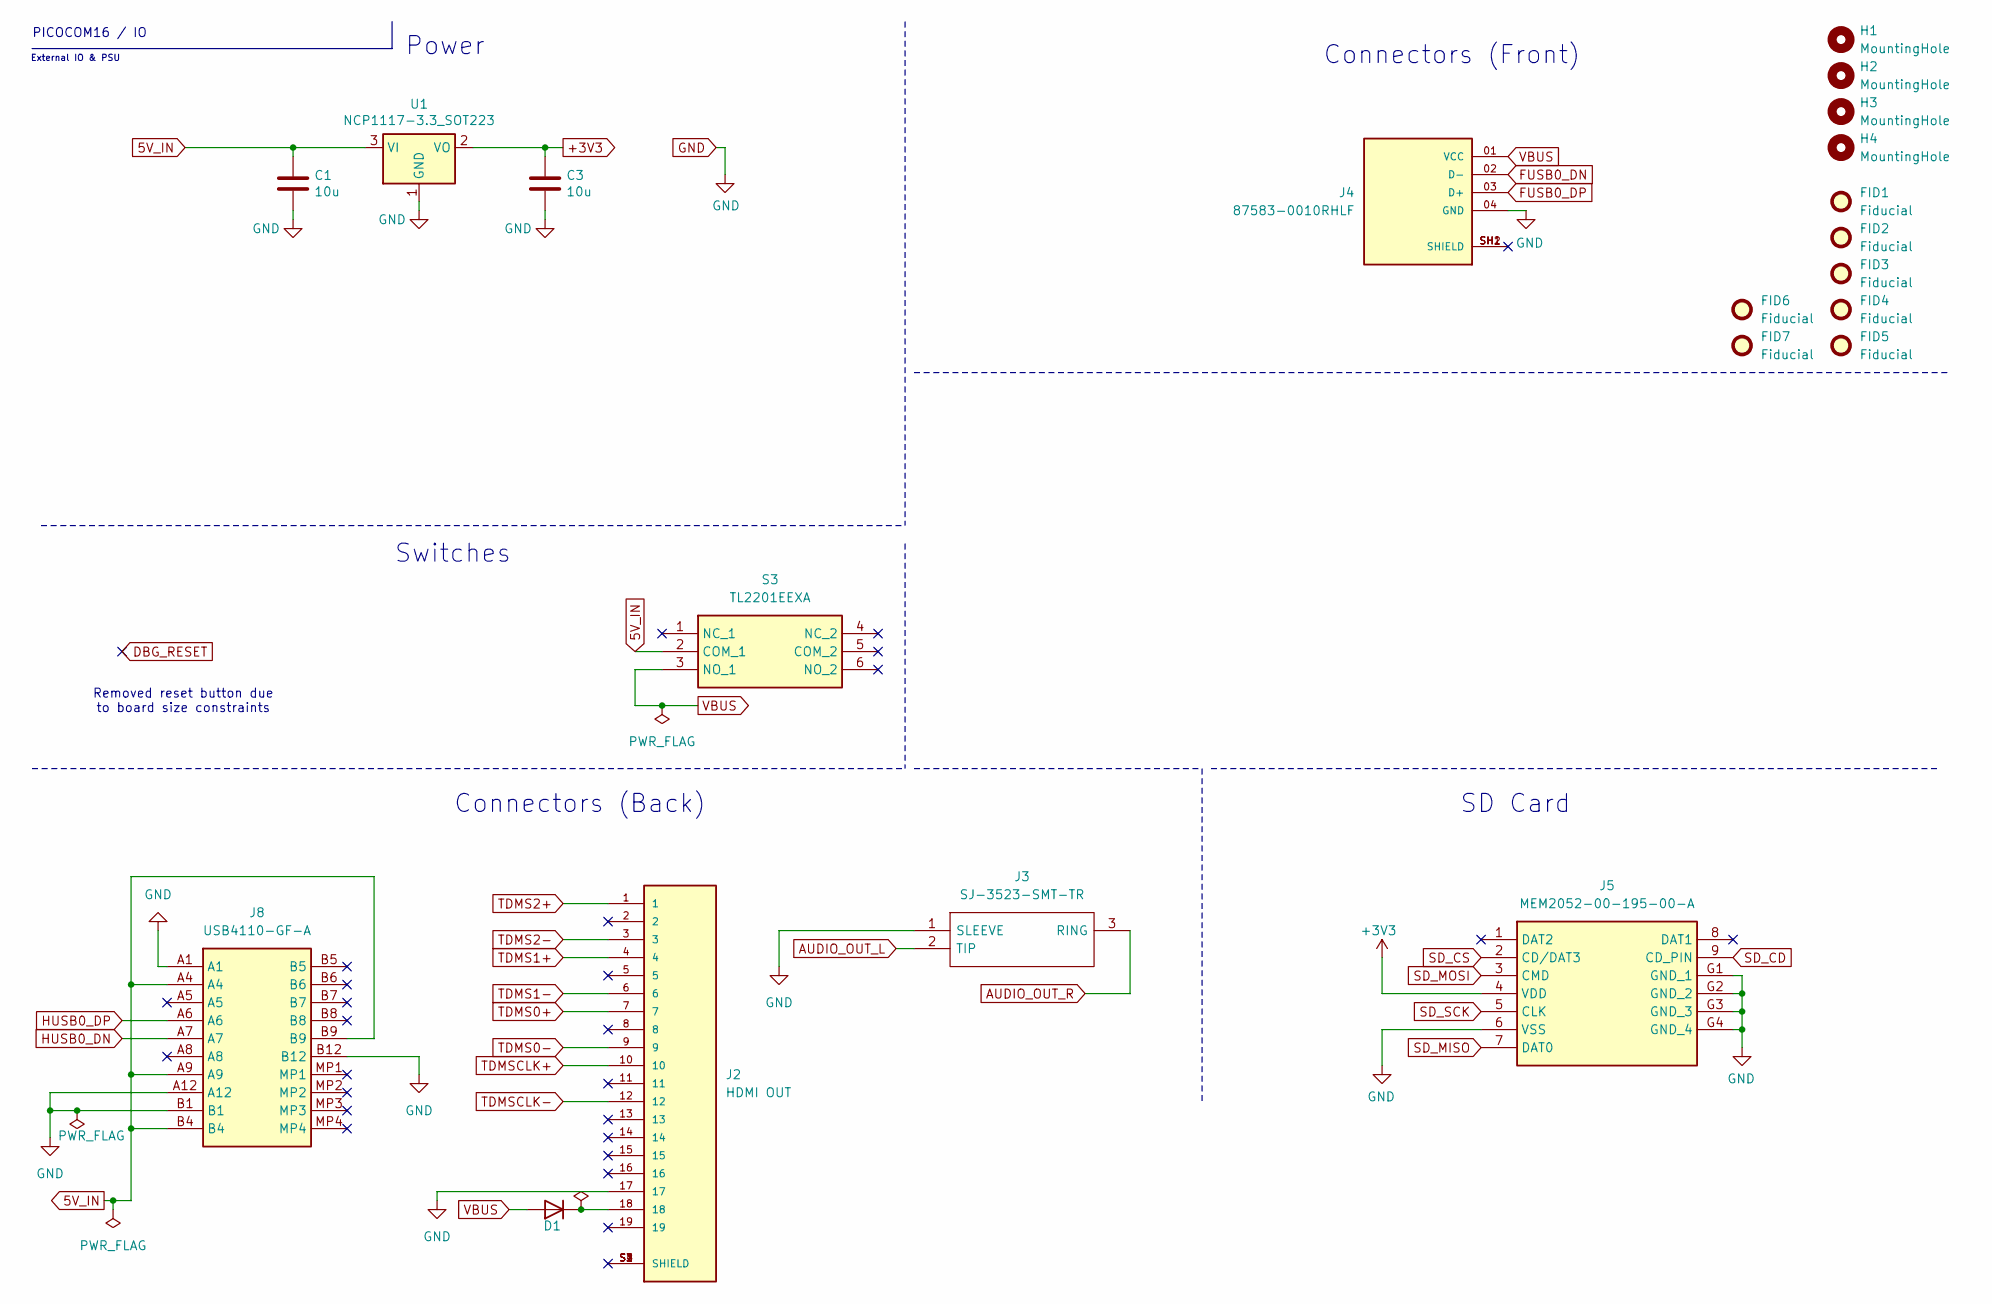
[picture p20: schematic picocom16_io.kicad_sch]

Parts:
C1, C3: 10u; C_0805_2012Metric
D1: D; SODFL1608X70N
FID1, FID2, FID3, FID4, FID6, FID7: Fiducial; Fiducial_1mm_Mask2mm
FID5: Fiducial; Fiducial_0.5mm_Mask1.5mm
H1, H2, H3, H4: MountingHole; MountingHole_2.7mm_M2.5
J2: HDMI OUT; STEWART_SS-53000-001; PARTREV A0
J3: SJ-3523-SMT-TR; SJ3523SMTTR; Mouser Part Number 490-SJ-3523-SMT-TR
J4: 87583-0010RHLF; AMPHENOL_87583-0010RHLF; PARTREV AD
J5: MEM2052-00-195-00-A; MEM20520019500A; Mouser Part Number 640-MEM20520019500A
J8: USB4110-GF-A; USB4110GFA; Mouser Part Number 640-USB4110-GF-A
S3: TL2201EEXA; Mouser Part Number 612-TL2201EEXA
U1: NCP1117-3.3_SOT223; SOT-223-3_TabPin2

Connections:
5V_IN: C1.1, J8.A4, J8.A9, J8.B4, J8.B9, S3.2 (COM_1), U1.3 (VI)
+3V3: C3.1, J5.4 (VDD), U1.2 (VO); also elsewhere on the board
AUDIO_OUT_L: J3.2 (TIP); also elsewhere on the board
AUDIO_OUT_R: J3.3 (RING); also elsewhere on the board
FUSB0_DN: J4.02 (D-); also elsewhere on the board
FUSB0_DP: J4.03 (D+); also elsewhere on the board
GND: C1.2, C3.2, J2.17, J3.1 (SLEEVE), J4.04 (GND), J5.6 (VSS), J5.G1 (GND_1), J5.G2 (GND_2), J5.G3 (GND_3), J5.G4 (GND_4), J8.A1, J8.A12, J8.B1, J8.B12, U1.1 (GND); also elsewhere on the board
HUSB0_DN: J8.A7; also elsewhere on the board
HUSB0_DP: J8.A6; also elsewhere on the board
unnamed: D1.1 (K), J2.18
SD_CD: J5.9 (CD_PIN); also elsewhere on the board
SD_CS: J5.2 (CD/DAT3); also elsewhere on the board
SD_MISO: J5.7 (DAT0); also elsewhere on the board
SD_MOSI: J5.3 (CMD); also elsewhere on the board
SD_SCK: J5.5 (CLK); also elsewhere on the board
TDMS0+: J2.7; also elsewhere on the board
TDMS0-: J2.9; also elsewhere on the board
TDMS1+: J2.4; also elsewhere on the board
TDMS1-: J2.6; also elsewhere on the board
TDMS2+: J2.1; also elsewhere on the board
TDMS2-: J2.3; also elsewhere on the board
TDMSCLK+: J2.10; also elsewhere on the board
TDMSCLK-: J2.12; also elsewhere on the board
VBUS: D1.2 (A), J4.01 (VCC), S3.3 (NO_1)

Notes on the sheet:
External IO & PSU
PICOCOM16 / IO
Power
Connectors (Front)
Switches
Removed reset button due to board size constraints
Connectors (Back)
SD Card

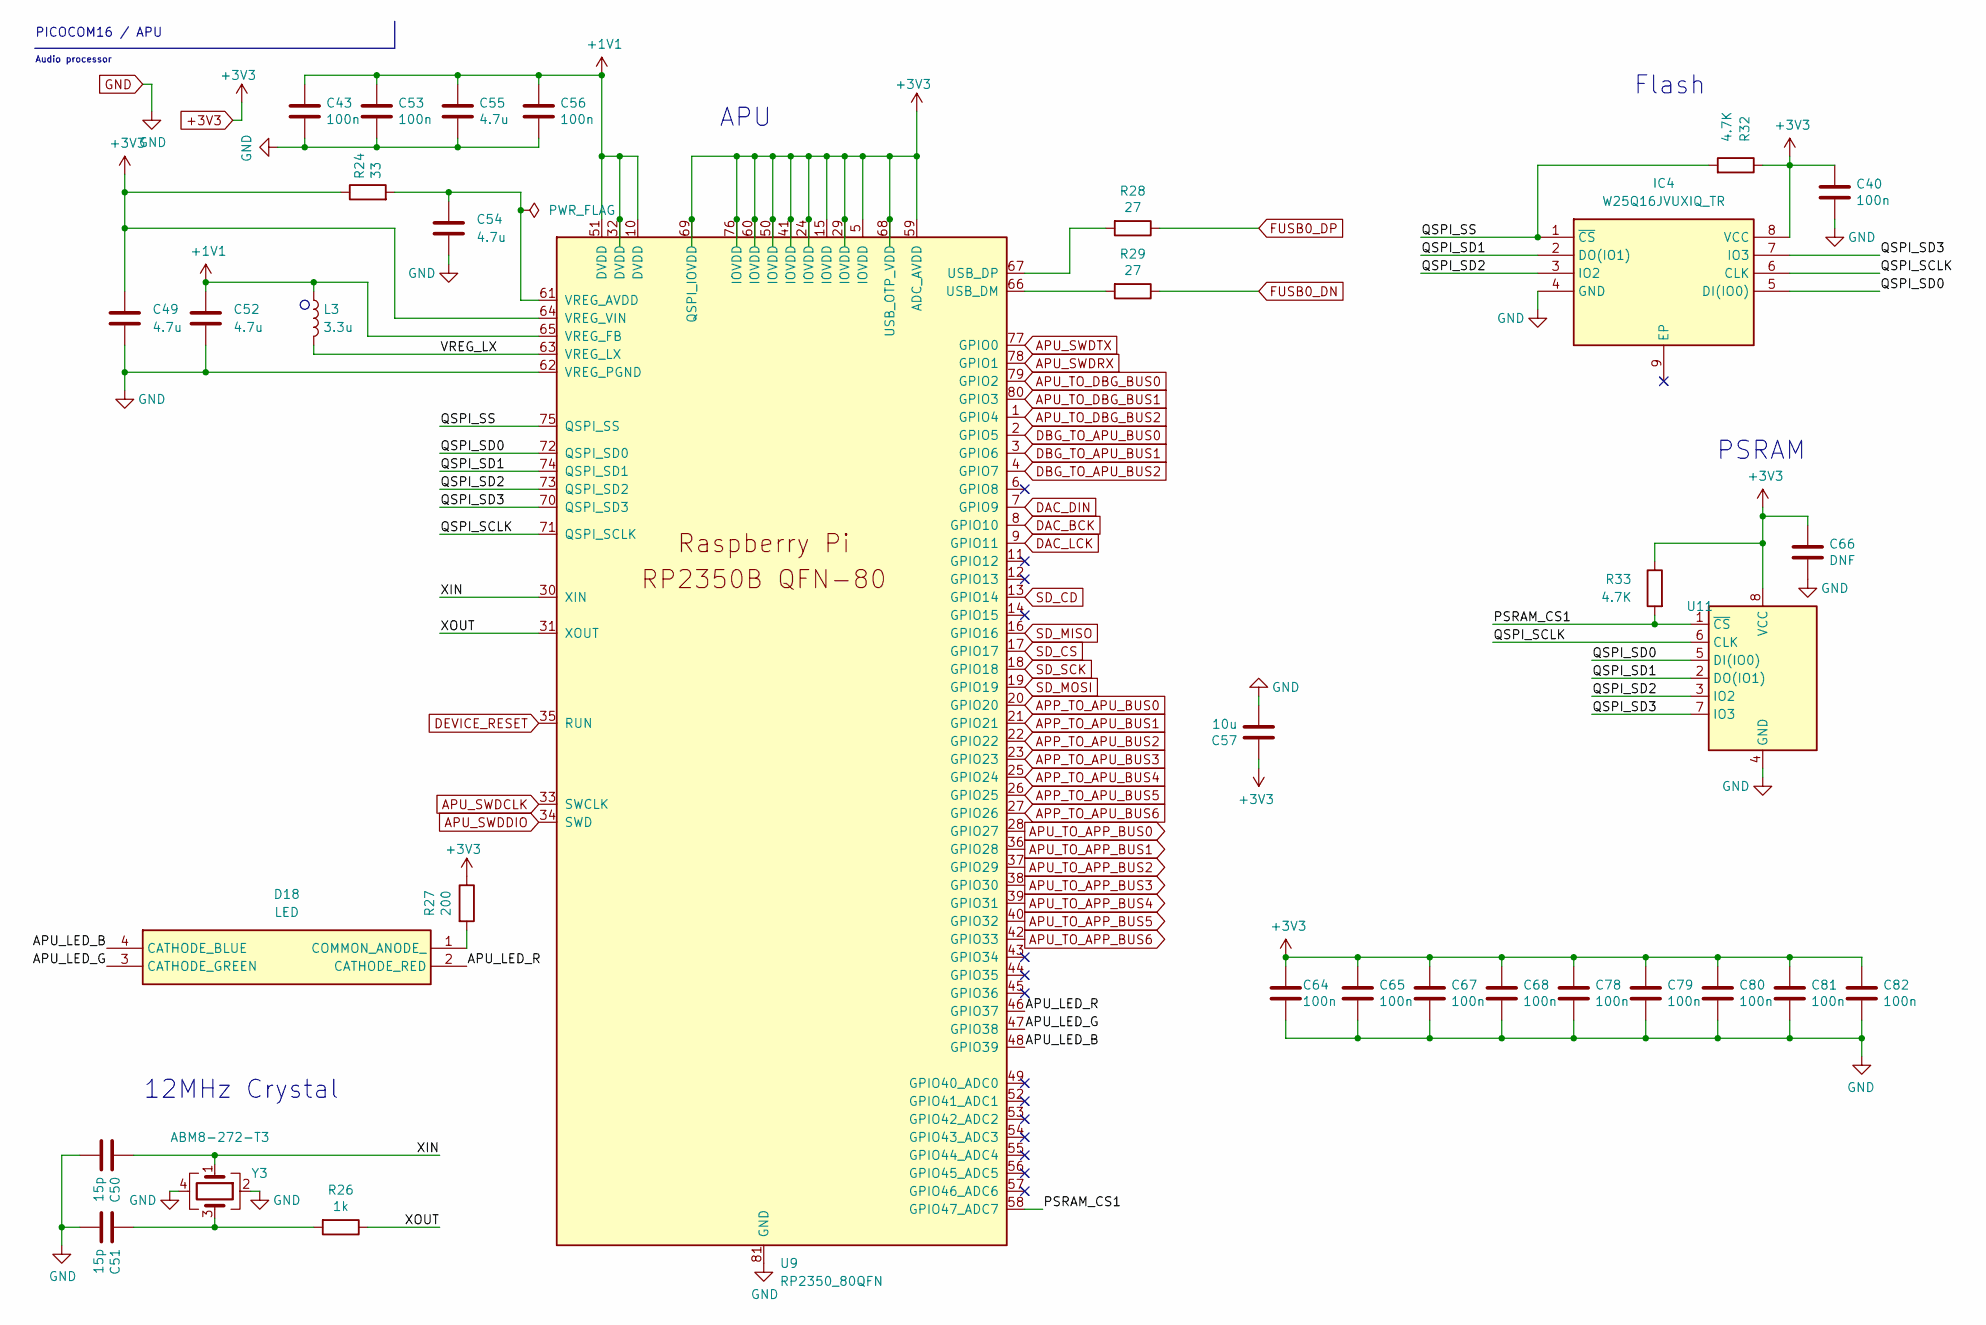
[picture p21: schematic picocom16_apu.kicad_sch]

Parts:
C40, C43, C53, C56, C64, C65, C67, C68, C78, C79, C80, C81, C82: 100n; C_0402_1005Metric
C49, C52, C54, C55: 4.7u; C_0402_1005Metric
C50, C51: 15p; C_0402_1005Metric
C57: 10u; C_0805_2012Metric
C66: DNF; C_0402_1005Metric
D18: LRTBR48G-P9Q7-1+R7S5-26+NP-68; LRTBR48GP9Q71R7S526NP68; Mouser Part Number 720-LRTBR48GP9A3521
IC4: W25Q16JVUXIQ_TR; SON50P300X200X60-9N; Mouser Part Number 454-W25Q16JVUXIQTR
L3: 3.3u; L_0805_2012Metric
R24: 33; R_0402_1005Metric
R26: 1k; R_0402_1005Metric
R27: 200; R_0402_1005Metric
R28, R29: 27; R_0402_1005Metric
R32, R33: 4.7K; R_0402_1005Metric
U9: RP2350_80QFN; RP2350-QFN-80-1EP_10x10_P0.4mm_EP3.4x3.4mm_ThermalVias
U11: SOIC-8_5.23x5.23mm_P1.27mm
Y3: ABM8-272-T3; ABM8272T3

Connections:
+1V1: C43.1, C52.1, C53.1, C55.1, C56.1, L3.1, U9.10 (DVDD), U9.32 (DVDD), U9.51 (DVDD), U9.65 (VREG_FB); also elsewhere on the board
+3V3: C40.1, C49.1, C57.1, C64.1, C65.1, C66.1, C67.1, C68.1, C78.1, C79.1, C80.1, C81.1, C82.1, IC4.8 (VCC), R24.1, R27.1, R32.1, R33.1, U9.5 (IOVDD), U9.15 (IOVDD), U9.24 (IOVDD), U9.29 (IOVDD), U9.41 (IOVDD), U9.50 (IOVDD), U9.59 (ADC_AVDD), U9.60 (IOVDD), U9.64 (VREG_VIN), U9.68 (USB_OTP_VDD), U9.69 (QSPI_IOVDD), U9.76 (IOVDD), U11.8 (VCC); also elsewhere on the board
/APU/APU_LED_B: D18.4 (CATHODE_BLUE), U9.48 (GPIO39)
/APU/APU_LED_G: D18.3 (CATHODE_GREEN), U9.47 (GPIO38)
/APU/APU_LED_R: D18.2 (CATHODE_RED), U9.46 (GPIO37)
/APU/PSRAM_CS1: R33.2, U9.58 (GPIO47_ADC7), U11.1 (~CS)
/APU/QSPI_SCLK: IC4.6 (CLK), U9.71 (QSPI_SCLK), U11.6 (CLK)
/APU/QSPI_SD0: IC4.5 (DI(IO0)), U9.72 (QSPI_SD0), U11.5 (DI(IO0))
/APU/QSPI_SD1: IC4.2 (DO(IO1)), U9.74 (QSPI_SD1), U11.2 (DO(IO1))
/APU/QSPI_SD2: IC4.3 (IO2), U9.73 (QSPI_SD2), U11.3 (IO2)
/APU/QSPI_SD3: IC4.7 (IO3), U9.70 (QSPI_SD3), U11.7 (IO3)
/APU/QSPI_SS: IC4.1 (~CS), R32.2, U9.75 (QSPI_SS)
/APU/VREG_LX: L3.2, U9.63 (VREG_LX)
/APU/XIN: C50.1, U9.30 (XIN), Y3.1
/APU/XOUT: R26.1, U9.31 (XOUT)
APP_TO_APU_BUS0: U9.20 (GPIO20); also elsewhere on the board
APP_TO_APU_BUS1: U9.21 (GPIO21); also elsewhere on the board
APP_TO_APU_BUS2: U9.22 (GPIO22); also elsewhere on the board
APP_TO_APU_BUS3: U9.23 (GPIO23); also elsewhere on the board
APP_TO_APU_BUS4: U9.25 (GPIO24); also elsewhere on the board
APP_TO_APU_BUS5: U9.26 (GPIO25); also elsewhere on the board
APP_TO_APU_BUS6: U9.27 (GPIO26); also elsewhere on the board
APU_SWDCLK: U9.33 (SWCLK); also elsewhere on the board
APU_SWDDIO: U9.34 (SWD); also elsewhere on the board
APU_SWDRX: U9.78 (GPIO1); also elsewhere on the board
APU_SWDTX: U9.77 (GPIO0); also elsewhere on the board
APU_TO_APP_BUS0: U9.28 (GPIO27); also elsewhere on the board
APU_TO_APP_BUS1: U9.36 (GPIO28); also elsewhere on the board
APU_TO_APP_BUS2: U9.37 (GPIO29); also elsewhere on the board
APU_TO_APP_BUS3: U9.38 (GPIO30); also elsewhere on the board
APU_TO_APP_BUS4: U9.39 (GPIO31); also elsewhere on the board
APU_TO_APP_BUS5: U9.40 (GPIO32); also elsewhere on the board
APU_TO_APP_BUS6: U9.42 (GPIO33); also elsewhere on the board
APU_TO_DBG_BUS0: U9.79 (GPIO2); also elsewhere on the board
APU_TO_DBG_BUS1: U9.80 (GPIO3); also elsewhere on the board
APU_TO_DBG_BUS2: U9.1 (GPIO4); also elsewhere on the board
DAC_BCK: U9.8 (GPIO10); also elsewhere on the board
DAC_DIN: U9.7 (GPIO9); also elsewhere on the board
DAC_LCK: U9.9 (GPIO11); also elsewhere on the board
DBG_TO_APU_BUS0: U9.2 (GPIO5); also elsewhere on the board
DBG_TO_APU_BUS1: U9.3 (GPIO6); also elsewhere on the board
DBG_TO_APU_BUS2: U9.4 (GPIO7); also elsewhere on the board
DEVICE_RESET: U9.35 (RUN); also elsewhere on the board
ESP_SPI_MISO: U9.44 (GPIO35)
ESP_SPI_MOSI: U9.43 (GPIO34)
FUSB0_DN: R29.1; also elsewhere on the board
FUSB0_DP: R28.1; also elsewhere on the board
GND: C40.2, C43.2, C49.2, C50.2, C51.2, C52.2, C53.2, C54.2, C55.2, C56.2, C57.2, C64.2, C65.2, C66.2, C67.2, C68.2, C78.2, C79.2, C80.2, C81.2, C82.2, IC4.4 (GND), U9.62 (VREG_PGND), U9.81 (GND), U11.4 (GND), Y3.2, Y3.4; also elsewhere on the board
unnamed: C51.1, R26.2, Y3.3
unnamed: D18.1 (COMMON_ANODE_), R27.2
unnamed: R29.2, U9.66 (USB_DM)
unnamed: R28.2, U9.67 (USB_DP)
unnamed: C54.1, R24.2, U9.61 (VREG_AVDD)
SD_CD: U9.13 (GPIO14); also elsewhere on the board
SD_CS: U9.17 (GPIO17); also elsewhere on the board
SD_MISO: U9.16 (GPIO16); also elsewhere on the board
SD_MOSI: U9.19 (GPIO19); also elsewhere on the board
SD_SCK: U9.18 (GPIO18); also elsewhere on the board

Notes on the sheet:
PSRAM
Flash
APU
12MHz Crystal
PICOCOM16 / APU
Audio processor

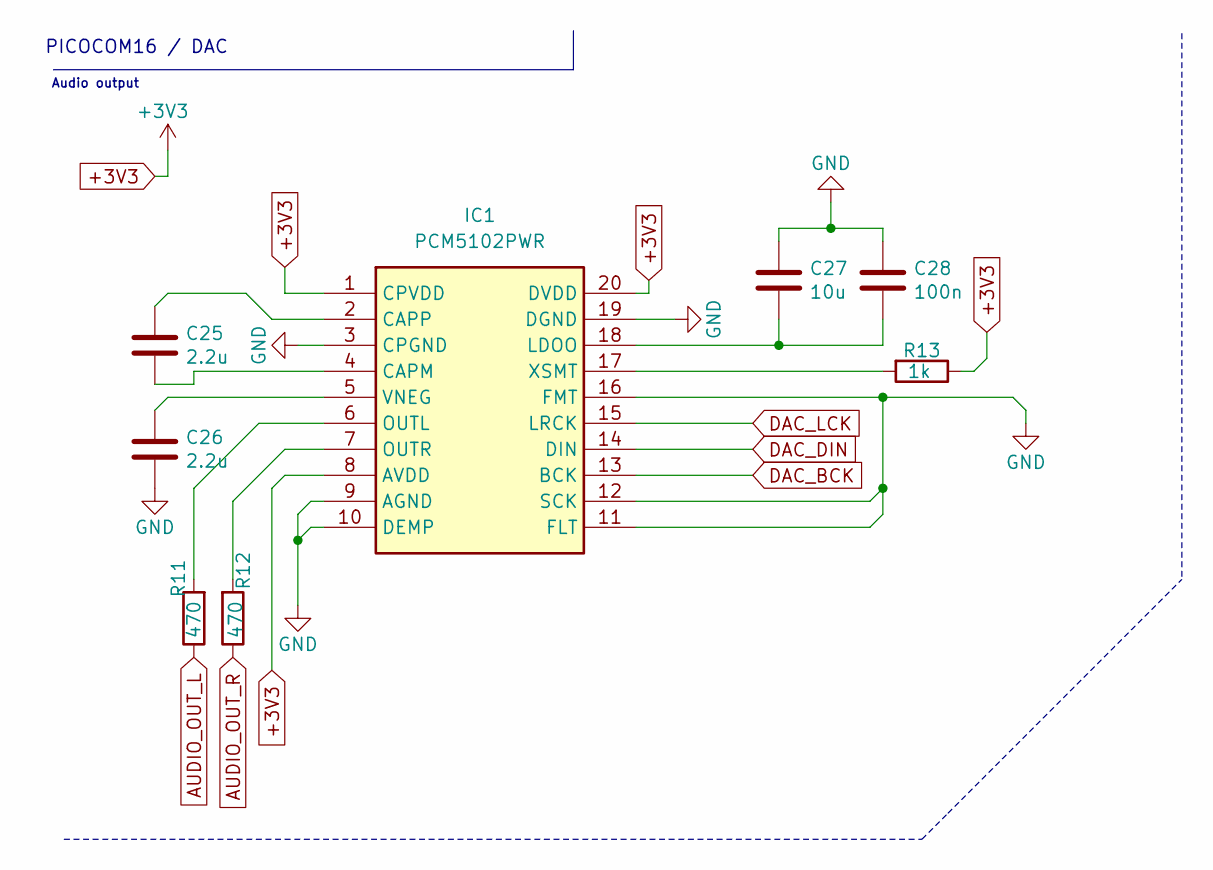
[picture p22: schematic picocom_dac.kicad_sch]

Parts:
C25, C26: 2.2u; C_0402_1005Metric
C27: 10u; C_0402_1005Metric
C28: 100n; C_0402_1005Metric
IC1: PCM5102PWR; SOP65P640X120-20N; Mouser Part Number 595-PCM5102PWR
R11, R12: 470; R_0402_1005Metric
R13: 1k; R_0402_1005Metric

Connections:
+3V3: IC1.1 (CPVDD), IC1.8 (AVDD), IC1.20 (DVDD), R13.1; also elsewhere on the board
AUDIO_OUT_L: R11.1; also elsewhere on the board
AUDIO_OUT_R: R12.1; also elsewhere on the board
DAC_BCK: IC1.13 (BCK); also elsewhere on the board
DAC_DIN: IC1.14 (DIN); also elsewhere on the board
DAC_LCK: IC1.15 (LRCK); also elsewhere on the board
GND: C26.2, C27.1, C28.1, IC1.3 (CPGND), IC1.9 (AGND), IC1.10 (DEMP), IC1.11 (FLT), IC1.12 (SCK), IC1.16 (FMT), IC1.19 (DGND); also elsewhere on the board
unnamed: C25.2, IC1.4 (CAPM)
unnamed: C25.1, IC1.2 (CAPP)
unnamed: C27.2, C28.2, IC1.18 (LDOO)
unnamed: IC1.6 (OUTL), R11.2
unnamed: IC1.7 (OUTR), R12.2
unnamed: C26.1, IC1.5 (VNEG)
unnamed: IC1.17 (XSMT), R13.2

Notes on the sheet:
PICOCOM16 / DAC
Audio output

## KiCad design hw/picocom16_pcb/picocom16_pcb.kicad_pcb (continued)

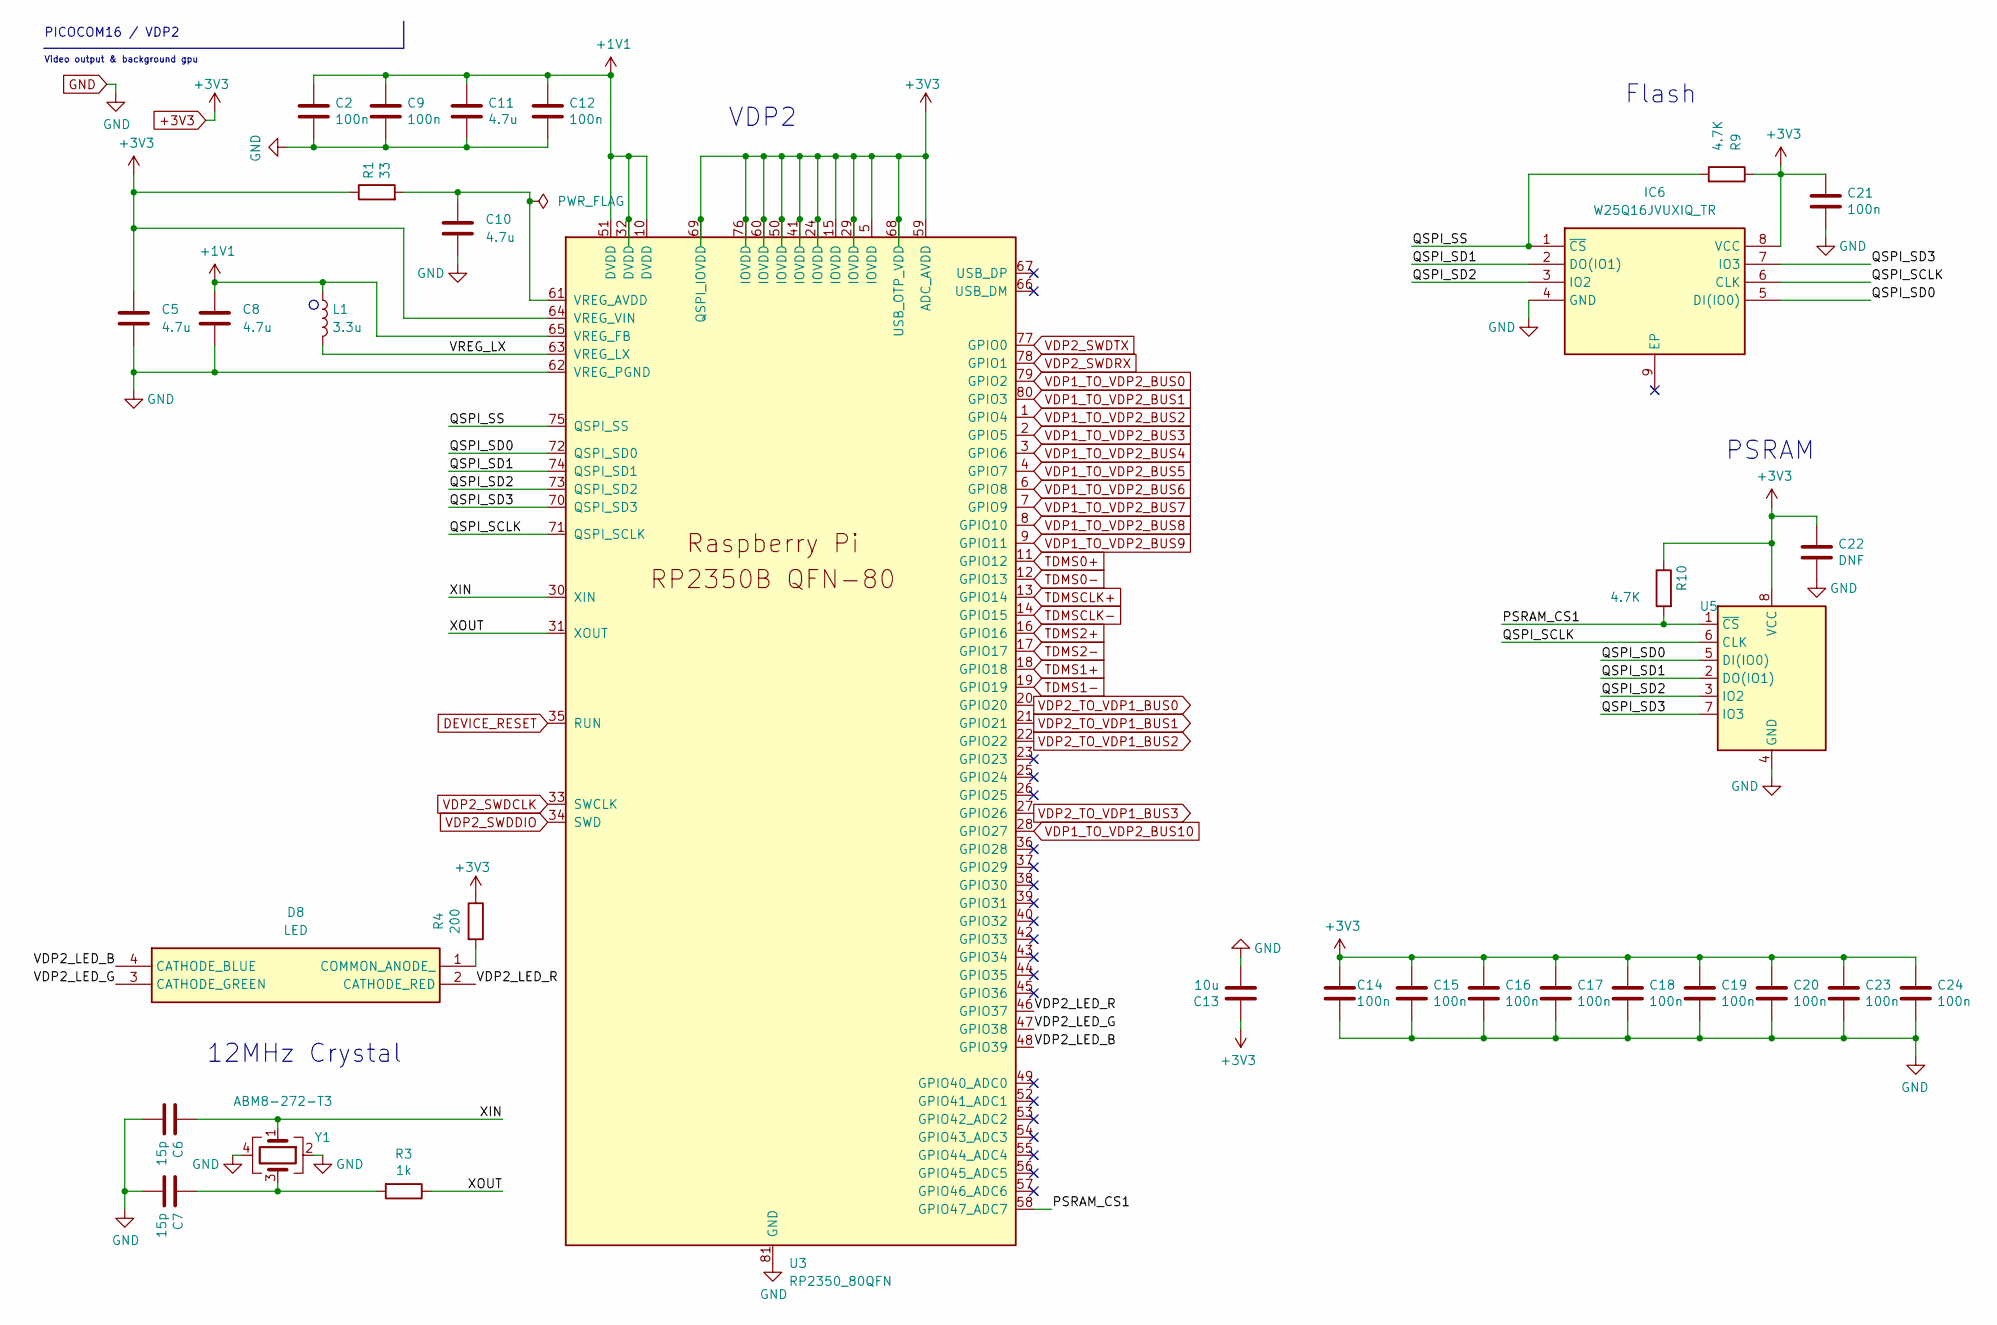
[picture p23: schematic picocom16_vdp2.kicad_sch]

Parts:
C2, C9, C12, C14, C15, C16, C17, C18, C19, C20, C21, C23, C24: 100n; C_0402_1005Metric
C5, C8, C10, C11: 4.7u; C_0402_1005Metric
C6, C7: 15p; C_0402_1005Metric
C13: 10u; C_0805_2012Metric
C22: DNF; C_0402_1005Metric
D8: LRTBR48G-P9Q7-1+R7S5-26+NP-68; LRTBR48GP9Q71R7S526NP68; Mouser Part Number 720-LRTBR48GP9A3521
IC6: W25Q16JVUXIQ_TR; SON50P300X200X60-9N; Mouser Part Number 454-W25Q16JVUXIQTR
L1: 3.3u; L_0805_2012Metric
R1: 33; R_0402_1005Metric
R3: 1k; R_0402_1005Metric
R4: 200; R_0402_1005Metric
R9, R10: 4.7K; R_0402_1005Metric
U3: RP2350_80QFN; RP2350-QFN-80-1EP_10x10_P0.4mm_EP3.4x3.4mm_ThermalVias
U5: SOIC-8_5.23x5.23mm_P1.27mm
Y1: ABM8-272-T3; ABM8272T3

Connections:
+1V1: C2.1, C8.1, C9.1, C11.1, C12.1, L1.1, U3.10 (DVDD), U3.32 (DVDD), U3.51 (DVDD), U3.65 (VREG_FB); also elsewhere on the board
+3V3: C5.1, C13.1, C14.1, C15.1, C16.1, C17.1, C18.1, C19.1, C20.1, C21.1, C22.1, C23.1, C24.1, IC6.8 (VCC), R1.1, R4.1, R9.1, R10.1, U3.5 (IOVDD), U3.15 (IOVDD), U3.24 (IOVDD), U3.29 (IOVDD), U3.41 (IOVDD), U3.50 (IOVDD), U3.59 (ADC_AVDD), U3.60 (IOVDD), U3.64 (VREG_VIN), U3.68 (USB_OTP_VDD), U3.69 (QSPI_IOVDD), U3.76 (IOVDD), U5.8 (VCC); also elsewhere on the board
/VDP2/PSRAM_CS1: R10.2, U3.58 (GPIO47_ADC7), U5.1 (~CS)
/VDP2/QSPI_SCLK: IC6.6 (CLK), U3.71 (QSPI_SCLK), U5.6 (CLK)
/VDP2/QSPI_SD0: IC6.5 (DI(IO0)), U3.72 (QSPI_SD0), U5.5 (DI(IO0))
/VDP2/QSPI_SD1: IC6.2 (DO(IO1)), U3.74 (QSPI_SD1), U5.2 (DO(IO1))
/VDP2/QSPI_SD2: IC6.3 (IO2), U3.73 (QSPI_SD2), U5.3 (IO2)
/VDP2/QSPI_SD3: IC6.7 (IO3), U3.70 (QSPI_SD3), U5.7 (IO3)
/VDP2/QSPI_SS: IC6.1 (~CS), R9.2, U3.75 (QSPI_SS)
/VDP2/VDP2_LED_B: D8.4 (CATHODE_BLUE), U3.48 (GPIO39)
/VDP2/VDP2_LED_G: D8.3 (CATHODE_GREEN), U3.47 (GPIO38)
/VDP2/VDP2_LED_R: D8.2 (CATHODE_RED), U3.46 (GPIO37)
/VDP2/VREG_LX: L1.2, U3.63 (VREG_LX)
/VDP2/XIN: C6.1, U3.30 (XIN), Y1.1
/VDP2/XOUT: R3.1, U3.31 (XOUT)
DEVICE_RESET: U3.35 (RUN); also elsewhere on the board
GND: C2.2, C5.2, C6.2, C7.2, C8.2, C9.2, C10.2, C11.2, C12.2, C13.2, C14.2, C15.2, C16.2, C17.2, C18.2, C19.2, C20.2, C21.2, C22.2, C23.2, C24.2, IC6.4 (GND), U3.62 (VREG_PGND), U3.81 (GND), U5.4 (GND), Y1.2, Y1.4; also elsewhere on the board
unnamed: C7.1, R3.2, Y1.3
unnamed: D8.1 (COMMON_ANODE_), R4.2
unnamed: C10.1, R1.2, U3.61 (VREG_AVDD)
TDMS0+: U3.11 (GPIO12); also elsewhere on the board
TDMS0-: U3.12 (GPIO13); also elsewhere on the board
TDMS1+: U3.18 (GPIO18); also elsewhere on the board
TDMS1-: U3.19 (GPIO19); also elsewhere on the board
TDMS2+: U3.16 (GPIO16); also elsewhere on the board
TDMS2-: U3.17 (GPIO17); also elsewhere on the board
TDMSCLK+: U3.13 (GPIO14); also elsewhere on the board
TDMSCLK-: U3.14 (GPIO15); also elsewhere on the board
VDP1_TO_VDP2_BUS0: U3.79 (GPIO2); also elsewhere on the board
VDP1_TO_VDP2_BUS1: U3.80 (GPIO3); also elsewhere on the board
VDP1_TO_VDP2_BUS2: U3.1 (GPIO4); also elsewhere on the board
VDP1_TO_VDP2_BUS3: U3.2 (GPIO5); also elsewhere on the board
VDP1_TO_VDP2_BUS4: U3.3 (GPIO6); also elsewhere on the board
VDP1_TO_VDP2_BUS5: U3.4 (GPIO7); also elsewhere on the board
VDP1_TO_VDP2_BUS6: U3.6 (GPIO8); also elsewhere on the board
VDP1_TO_VDP2_BUS7: U3.7 (GPIO9); also elsewhere on the board
VDP1_TO_VDP2_BUS8: U3.8 (GPIO10); also elsewhere on the board
VDP1_TO_VDP2_BUS9: U3.9 (GPIO11); also elsewhere on the board
VDP1_TO_VDP2_BUS10: U3.28 (GPIO27); also elsewhere on the board
VDP2_SWDCLK: U3.33 (SWCLK); also elsewhere on the board
VDP2_SWDDIO: U3.34 (SWD); also elsewhere on the board
VDP2_SWDRX: U3.78 (GPIO1); also elsewhere on the board
VDP2_SWDTX: U3.77 (GPIO0); also elsewhere on the board
VDP2_TO_VDP1_BUS0: U3.20 (GPIO20); also elsewhere on the board
VDP2_TO_VDP1_BUS1: U3.21 (GPIO21); also elsewhere on the board
VDP2_TO_VDP1_BUS2: U3.22 (GPIO22); also elsewhere on the board
VDP2_TO_VDP1_BUS3: U3.27 (GPIO26); also elsewhere on the board

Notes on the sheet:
PSRAM
Flash
VDP2
12MHz Crystal
PICOCOM16 / VDP2
Video output & background gpu

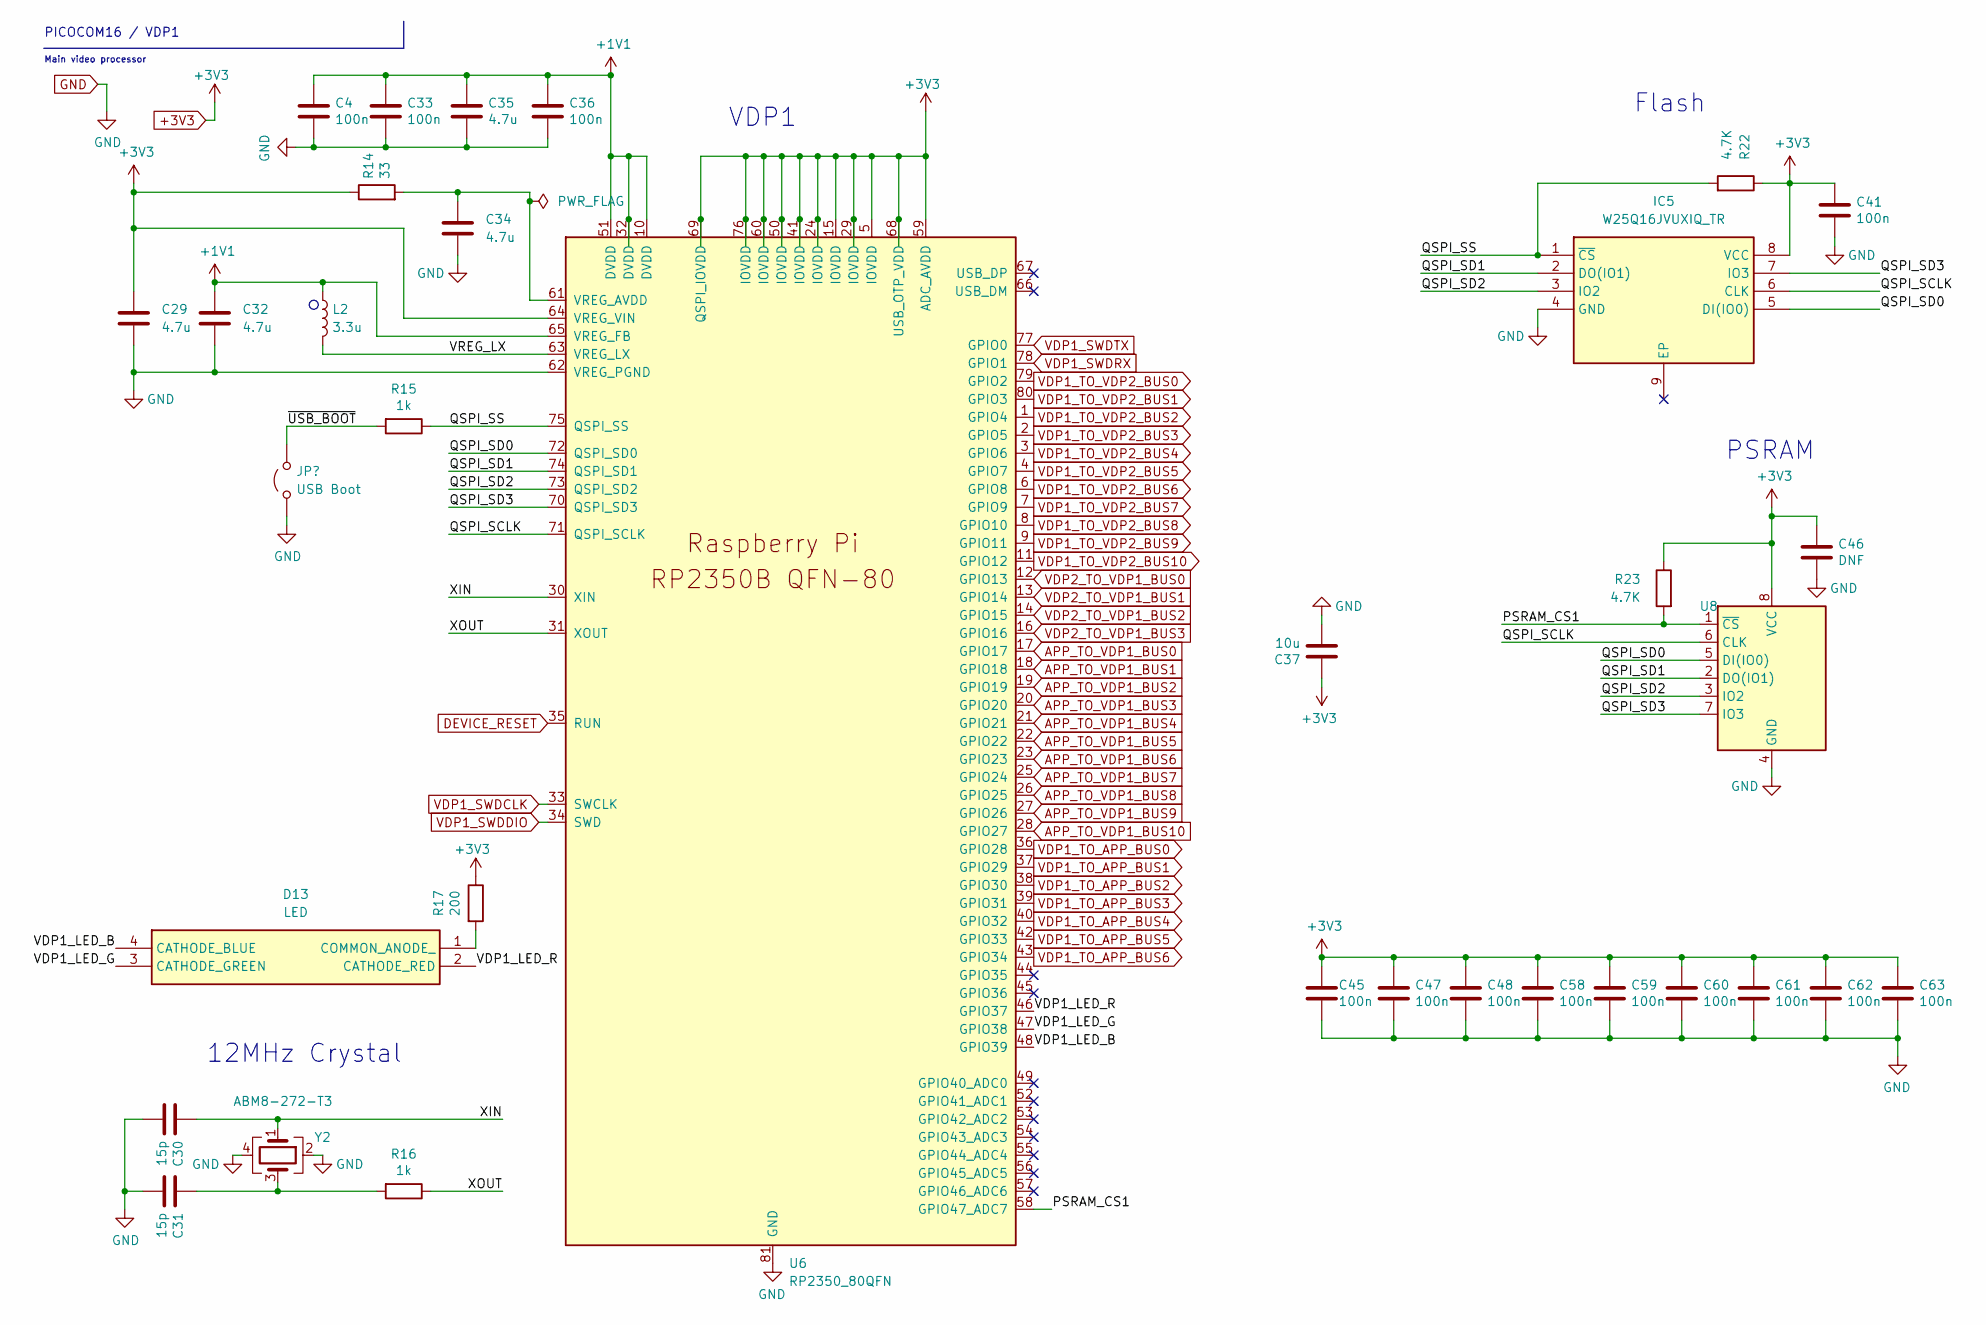
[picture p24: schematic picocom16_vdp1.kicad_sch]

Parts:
C4, C33, C36, C41, C45, C47, C48, C58, C59, C60, C61, C62, C63: 100n; C_0402_1005Metric
C29, C32, C34, C35: 4.7u; C_0402_1005Metric
C30, C31: 15p; C_0402_1005Metric
C37: 10u; C_0805_2012Metric
C46: DNF; C_0402_1005Metric
D13: LRTBR48G-P9Q7-1+R7S5-26+NP-68; LRTBR48GP9Q71R7S526NP68; Mouser Part Number 720-LRTBR48GP9A3521
IC5: W25Q16JVUXIQ_TR; SON50P300X200X60-9N; Mouser Part Number 454-W25Q16JVUXIQTR
JP2: USB Boot; SolderJumper-2_P1.3mm_Open_Pad1.0x1.5mm
L2: 3.3u; L_0805_2012Metric
R14: 33; R_0402_1005Metric
R15, R16: 1k; R_0402_1005Metric
R17: 200; R_0402_1005Metric
R22, R23: 4.7K; R_0402_1005Metric
U6: RP2350_80QFN; RP2350-QFN-80-1EP_10x10_P0.4mm_EP3.4x3.4mm_ThermalVias
U8: SOIC-8_5.23x5.23mm_P1.27mm
Y2: ABM8-272-T3; ABM8272T3

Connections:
+1V1: C4.1, C32.1, C33.1, C35.1, C36.1, L2.1, U6.10 (DVDD), U6.32 (DVDD), U6.51 (DVDD), U6.65 (VREG_FB); also elsewhere on the board
+3V3: C29.1, C37.1, C41.1, C45.1, C46.1, C47.1, C48.1, C58.1, C59.1, C60.1, C61.1, C62.1, C63.1, IC5.8 (VCC), R14.1, R17.1, R22.1, R23.1, U6.5 (IOVDD), U6.15 (IOVDD), U6.24 (IOVDD), U6.29 (IOVDD), U6.41 (IOVDD), U6.50 (IOVDD), U6.59 (ADC_AVDD), U6.60 (IOVDD), U6.64 (VREG_VIN), U6.68 (USB_OTP_VDD), U6.69 (QSPI_IOVDD), U6.76 (IOVDD), U8.8 (VCC); also elsewhere on the board
/VDP1/PSRAM_CS1: R23.2, U6.58 (GPIO47_ADC7), U8.1 (~CS)
/VDP1/QSPI_SCLK: IC5.6 (CLK), U6.71 (QSPI_SCLK), U8.6 (CLK)
/VDP1/QSPI_SD0: IC5.5 (DI(IO0)), U6.72 (QSPI_SD0), U8.5 (DI(IO0))
/VDP1/QSPI_SD1: IC5.2 (DO(IO1)), U6.74 (QSPI_SD1), U8.2 (DO(IO1))
/VDP1/QSPI_SD2: IC5.3 (IO2), U6.73 (QSPI_SD2), U8.3 (IO2)
/VDP1/QSPI_SD3: IC5.7 (IO3), U6.70 (QSPI_SD3), U8.7 (IO3)
/VDP1/QSPI_SS: IC5.1 (~CS), R15.1, R22.2, U6.75 (QSPI_SS)
/VDP1/VDP1_LED_B: D13.4 (CATHODE_BLUE), U6.48 (GPIO39)
/VDP1/VDP1_LED_G: D13.3 (CATHODE_GREEN), U6.47 (GPIO38)
/VDP1/VDP1_LED_R: D13.2 (CATHODE_RED), U6.46 (GPIO37)
/VDP1/VREG_LX: L2.2, U6.63 (VREG_LX)
/VDP1/XIN: C30.1, U6.30 (XIN), Y2.1
/VDP1/XOUT: R16.1, U6.31 (XOUT)
/VDP1/~USB_BOOT: JP2.2 (B), R15.2
APP_TO_VDP1_BUS0: U6.17 (GPIO17); also elsewhere on the board
APP_TO_VDP1_BUS1: U6.18 (GPIO18); also elsewhere on the board
APP_TO_VDP1_BUS2: U6.19 (GPIO19); also elsewhere on the board
APP_TO_VDP1_BUS3: U6.20 (GPIO20); also elsewhere on the board
APP_TO_VDP1_BUS4: U6.21 (GPIO21); also elsewhere on the board
APP_TO_VDP1_BUS5: U6.22 (GPIO22); also elsewhere on the board
APP_TO_VDP1_BUS6: U6.23 (GPIO23); also elsewhere on the board
APP_TO_VDP1_BUS7: U6.25 (GPIO24); also elsewhere on the board
APP_TO_VDP1_BUS8: U6.26 (GPIO25); also elsewhere on the board
APP_TO_VDP1_BUS9: U6.27 (GPIO26); also elsewhere on the board
APP_TO_VDP1_BUS10: U6.28 (GPIO27); also elsewhere on the board
DEVICE_RESET: U6.35 (RUN); also elsewhere on the board
GND: C4.2, C29.2, C30.2, C31.2, C32.2, C33.2, C34.2, C35.2, C36.2, C37.2, C41.2, C45.2, C46.2, C47.2, C48.2, C58.2, C59.2, C60.2, C61.2, C62.2, C63.2, IC5.4 (GND), JP2.1 (A), U6.62 (VREG_PGND), U6.81 (GND), U8.4 (GND), Y2.2, Y2.4; also elsewhere on the board
unnamed: C31.1, R16.2, Y2.3
unnamed: D13.1 (COMMON_ANODE_), R17.2
unnamed: C34.1, R14.2, U6.61 (VREG_AVDD)
VDP1_SWDCLK: U6.33 (SWCLK); also elsewhere on the board
VDP1_SWDDIO: U6.34 (SWD); also elsewhere on the board
VDP1_SWDRX: U6.78 (GPIO1); also elsewhere on the board
VDP1_SWDTX: U6.77 (GPIO0); also elsewhere on the board
VDP1_TO_APP_BUS0: U6.36 (GPIO28); also elsewhere on the board
VDP1_TO_APP_BUS1: U6.37 (GPIO29); also elsewhere on the board
VDP1_TO_APP_BUS2: U6.38 (GPIO30); also elsewhere on the board
VDP1_TO_APP_BUS3: U6.39 (GPIO31); also elsewhere on the board
VDP1_TO_APP_BUS4: U6.40 (GPIO32); also elsewhere on the board
VDP1_TO_APP_BUS5: U6.42 (GPIO33); also elsewhere on the board
VDP1_TO_APP_BUS6: U6.43 (GPIO34); also elsewhere on the board
VDP1_TO_VDP2_BUS0: U6.79 (GPIO2); also elsewhere on the board
VDP1_TO_VDP2_BUS1: U6.80 (GPIO3); also elsewhere on the board
VDP1_TO_VDP2_BUS2: U6.1 (GPIO4); also elsewhere on the board
VDP1_TO_VDP2_BUS3: U6.2 (GPIO5); also elsewhere on the board
VDP1_TO_VDP2_BUS4: U6.3 (GPIO6); also elsewhere on the board
VDP1_TO_VDP2_BUS5: U6.4 (GPIO7); also elsewhere on the board
VDP1_TO_VDP2_BUS6: U6.6 (GPIO8); also elsewhere on the board
VDP1_TO_VDP2_BUS7: U6.7 (GPIO9); also elsewhere on the board
VDP1_TO_VDP2_BUS8: U6.8 (GPIO10); also elsewhere on the board
VDP1_TO_VDP2_BUS9: U6.9 (GPIO11); also elsewhere on the board
VDP1_TO_VDP2_BUS10: U6.11 (GPIO12); also elsewhere on the board
VDP2_TO_VDP1_BUS0: U6.12 (GPIO13); also elsewhere on the board
VDP2_TO_VDP1_BUS1: U6.13 (GPIO14); also elsewhere on the board
VDP2_TO_VDP1_BUS2: U6.14 (GPIO15); also elsewhere on the board
VDP2_TO_VDP1_BUS3: U6.16 (GPIO16); also elsewhere on the board

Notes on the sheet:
PSRAM
Flash
VDP1
12MHz Crystal
PICOCOM16 / VDP1
Main video processor

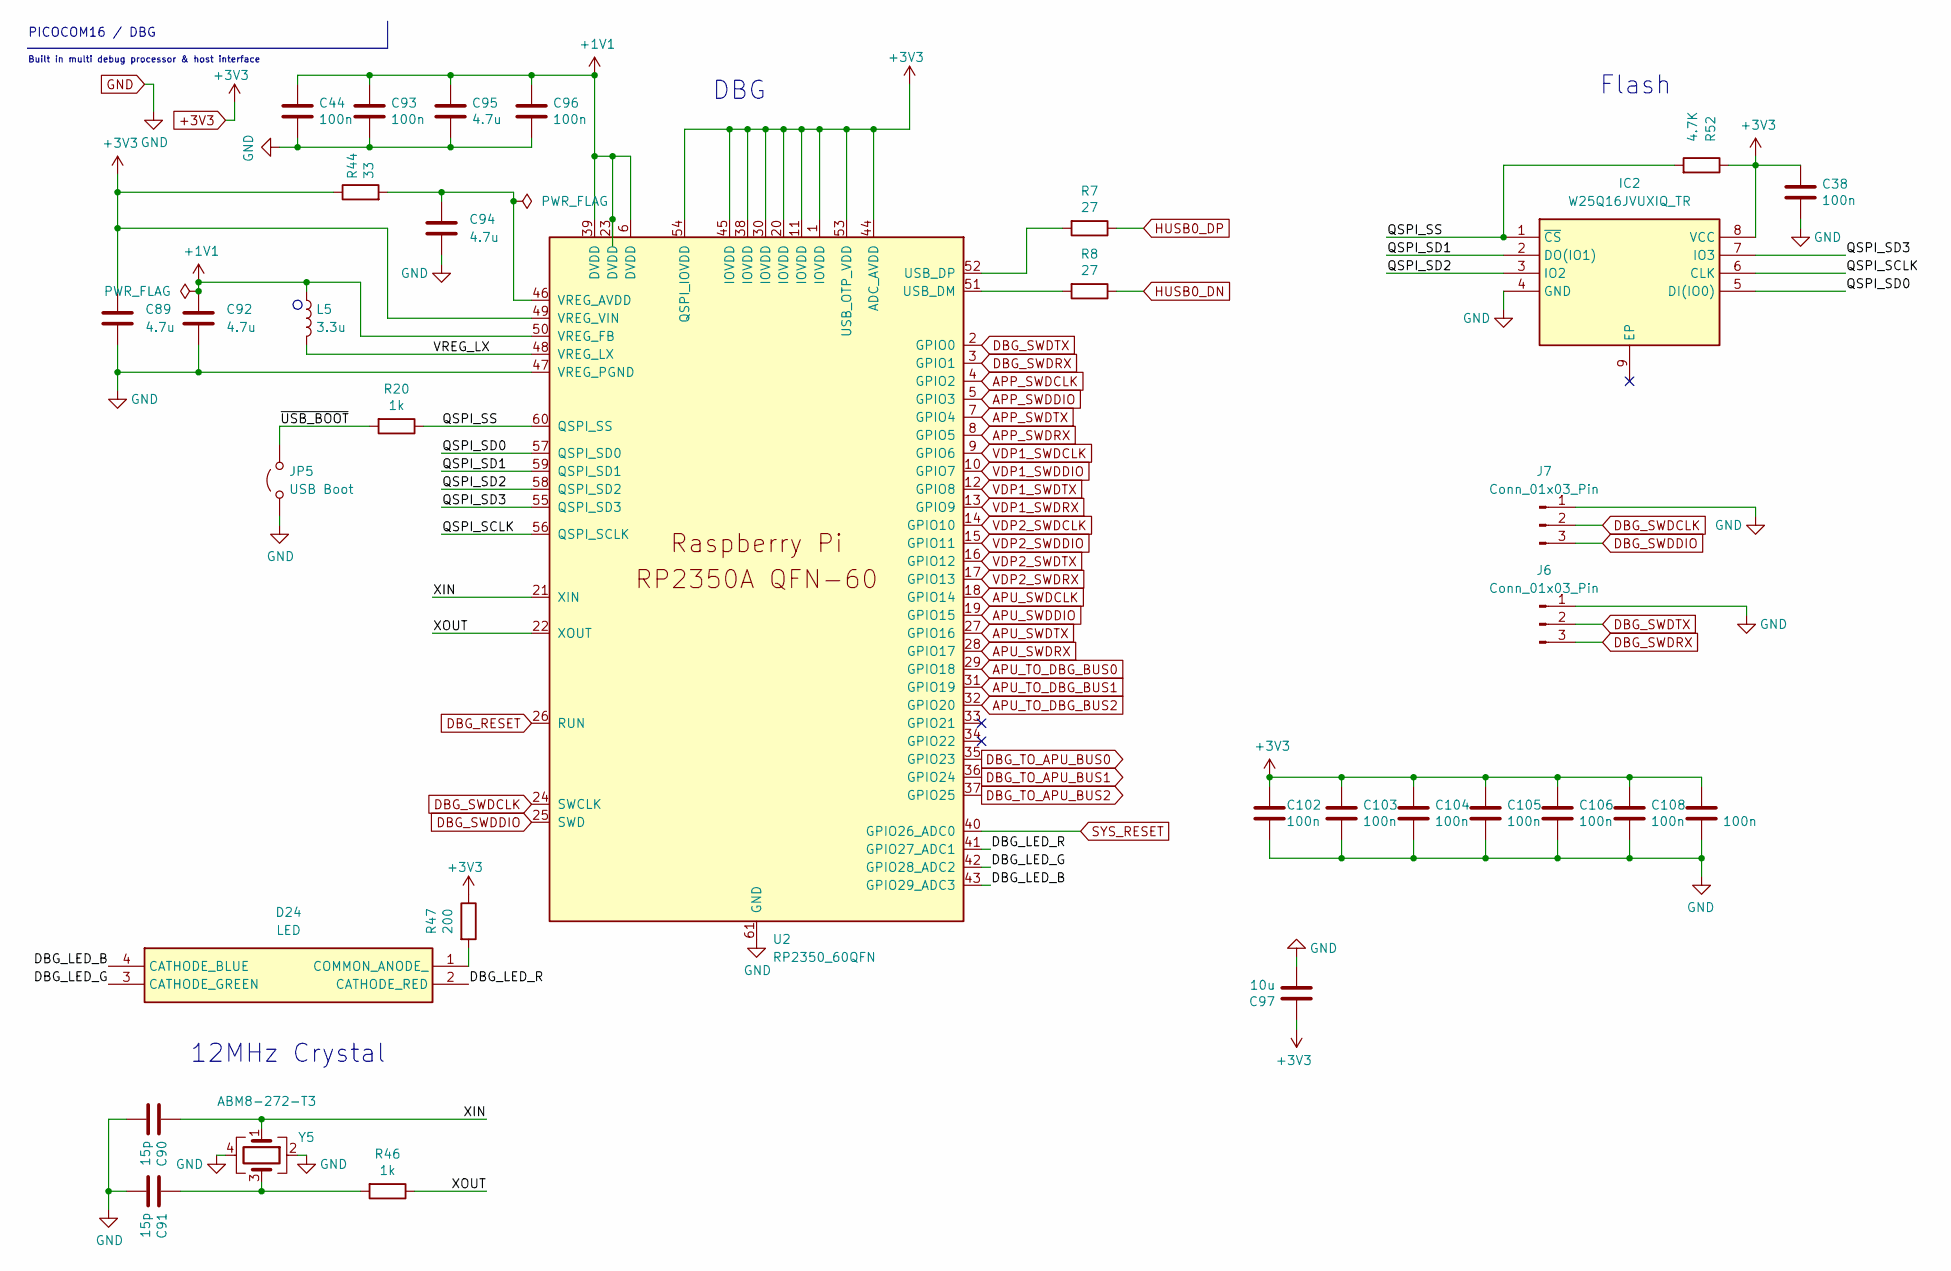
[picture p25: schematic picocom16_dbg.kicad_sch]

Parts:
C38, C44, C93, C96, C102, C103, C104, C105, C106, C108, C109: 100n; C_0402_1005Metric
C89, C92, C94, C95: 4.7u; C_0402_1005Metric
C90, C91: 15p; C_0402_1005Metric
C97: 10u; C_0805_2012Metric
D24: LRTBR48G-P9Q7-1+R7S5-26+NP-68; LRTBR48GP9Q71R7S526NP68; Mouser Part Number 720-LRTBR48GP9A3521
IC2: W25Q16JVUXIQ_TR; SON50P300X200X60-9N; Mouser Part Number 454-W25Q16JVUXIQTR
J6, J7: Conn_01x03_Pin; PinHeader_1x03_P2.54mm_Vertical_SMD_Pin1Left
JP5: USB Boot; SolderJumper-2_P1.3mm_Open_Pad1.0x1.5mm
L5: 3.3u; L_0805_2012Metric
R7, R8: 27; R_0402_1005Metric
R20, R46: 1k; R_0402_1005Metric
R44: 33; R_0402_1005Metric
R47: 200; R_0402_1005Metric
R52: 4.7K; R_0402_1005Metric
U2: RP2350_60QFN; QFN-60-1EP_7x7mm_P0.4mm_EP3.4x3.4mm
Y5: ABM8-272-T3; ABM8272T3

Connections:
+1V1: C44.1, C92.1, C93.1, C95.1, C96.1, L5.1, U2.6 (DVDD), U2.23 (DVDD), U2.39 (DVDD), U2.50 (VREG_FB); also elsewhere on the board
+3V3: C38.1, C89.1, C97.1, C102.1, C103.1, C104.1, C105.1, C106.1, C108.1, C109.1, IC2.8 (VCC), R44.1, R47.1, R52.1, U2.1 (IOVDD), U2.11 (IOVDD), U2.20 (IOVDD), U2.30 (IOVDD), U2.38 (IOVDD), U2.44 (ADC_AVDD), U2.45 (IOVDD), U2.49 (VREG_VIN), U2.53 (USB_OTP_VDD), U2.54 (QSPI_IOVDD); also elsewhere on the board
/DBG/DBG_LED_B: D24.4 (CATHODE_BLUE), U2.43 (GPIO29_ADC3)
/DBG/DBG_LED_G: D24.3 (CATHODE_GREEN), U2.42 (GPIO28_ADC2)
/DBG/DBG_LED_R: D24.2 (CATHODE_RED), U2.41 (GPIO27_ADC1)
/DBG/QSPI_SCLK: IC2.6 (CLK), U2.56 (QSPI_SCLK)
/DBG/QSPI_SD0: IC2.5 (DI(IO0)), U2.57 (QSPI_SD0)
/DBG/QSPI_SD1: IC2.2 (DO(IO1)), U2.59 (QSPI_SD1)
/DBG/QSPI_SD2: IC2.3 (IO2), U2.58 (QSPI_SD2)
/DBG/QSPI_SD3: IC2.7 (IO3), U2.55 (QSPI_SD3)
/DBG/QSPI_SS: IC2.1 (~CS), R20.1, R52.2, U2.60 (QSPI_SS)
/DBG/VREG_LX: L5.2, U2.48 (VREG_LX)
/DBG/XIN: C90.1, U2.21 (XIN), Y5.1
/DBG/XOUT: R46.1, U2.22 (XOUT)
/DBG/~USB_BOOT: JP5.2 (B), R20.2
APP_SWDCLK: U2.4 (GPIO2); also elsewhere on the board
APP_SWDDIO: U2.5 (GPIO3); also elsewhere on the board
APP_SWDRX: U2.8 (GPIO5); also elsewhere on the board
APP_SWDTX: U2.7 (GPIO4); also elsewhere on the board
APU_SWDCLK: U2.18 (GPIO14); also elsewhere on the board
APU_SWDDIO: U2.19 (GPIO15); also elsewhere on the board
APU_SWDRX: U2.28 (GPIO17); also elsewhere on the board
APU_SWDTX: U2.27 (GPIO16); also elsewhere on the board
APU_TO_DBG_BUS0: U2.29 (GPIO18); also elsewhere on the board
APU_TO_DBG_BUS1: U2.31 (GPIO19); also elsewhere on the board
APU_TO_DBG_BUS2: U2.32 (GPIO20); also elsewhere on the board
DBG_RESET: U2.26 (RUN)
DBG_SWDCLK: J7.2, U2.24 (SWCLK)
DBG_SWDDIO: J7.3, U2.25 (SWD)
DBG_SWDRX: J6.3, U2.3 (GPIO1)
DBG_SWDTX: J6.2, U2.2 (GPIO0)
DBG_TO_APU_BUS0: U2.35 (GPIO23); also elsewhere on the board
DBG_TO_APU_BUS1: U2.36 (GPIO24); also elsewhere on the board
DBG_TO_APU_BUS2: U2.37 (GPIO25); also elsewhere on the board
GND: C38.2, C44.2, C89.2, C90.2, C91.2, C92.2, C93.2, C94.2, C95.2, C96.2, C97.2, C102.2, C103.2, C104.2, C105.2, C106.2, C108.2, C109.2, IC2.4 (GND), J6.1, J7.1, JP5.1 (A), U2.47 (VREG_PGND), U2.61 (GND), Y5.2, Y5.4; also elsewhere on the board
HUSB0_DN: R8.1; also elsewhere on the board
HUSB0_DP: R7.1; also elsewhere on the board
unnamed: C91.1, R46.2, Y5.3
unnamed: D24.1 (COMMON_ANODE_), R47.2
unnamed: R8.2, U2.51 (USB_DM)
unnamed: R7.2, U2.52 (USB_DP)
unnamed: C94.1, R44.2, U2.46 (VREG_AVDD)
SYS_RESET: U2.40 (GPIO26_ADC0); also elsewhere on the board
VDP1_SWDCLK: U2.9 (GPIO6); also elsewhere on the board
VDP1_SWDDIO: U2.10 (GPIO7); also elsewhere on the board
VDP1_SWDRX: U2.13 (GPIO9); also elsewhere on the board
VDP1_SWDTX: U2.12 (GPIO8); also elsewhere on the board
VDP2_SWDCLK: U2.14 (GPIO10); also elsewhere on the board
VDP2_SWDDIO: U2.15 (GPIO11); also elsewhere on the board
VDP2_SWDRX: U2.17 (GPIO13); also elsewhere on the board
VDP2_SWDTX: U2.16 (GPIO12); also elsewhere on the board

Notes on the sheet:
DBG
Flash
12MHz Crystal
PICOCOM16 / DBG
Built in multi debug processor & host interface

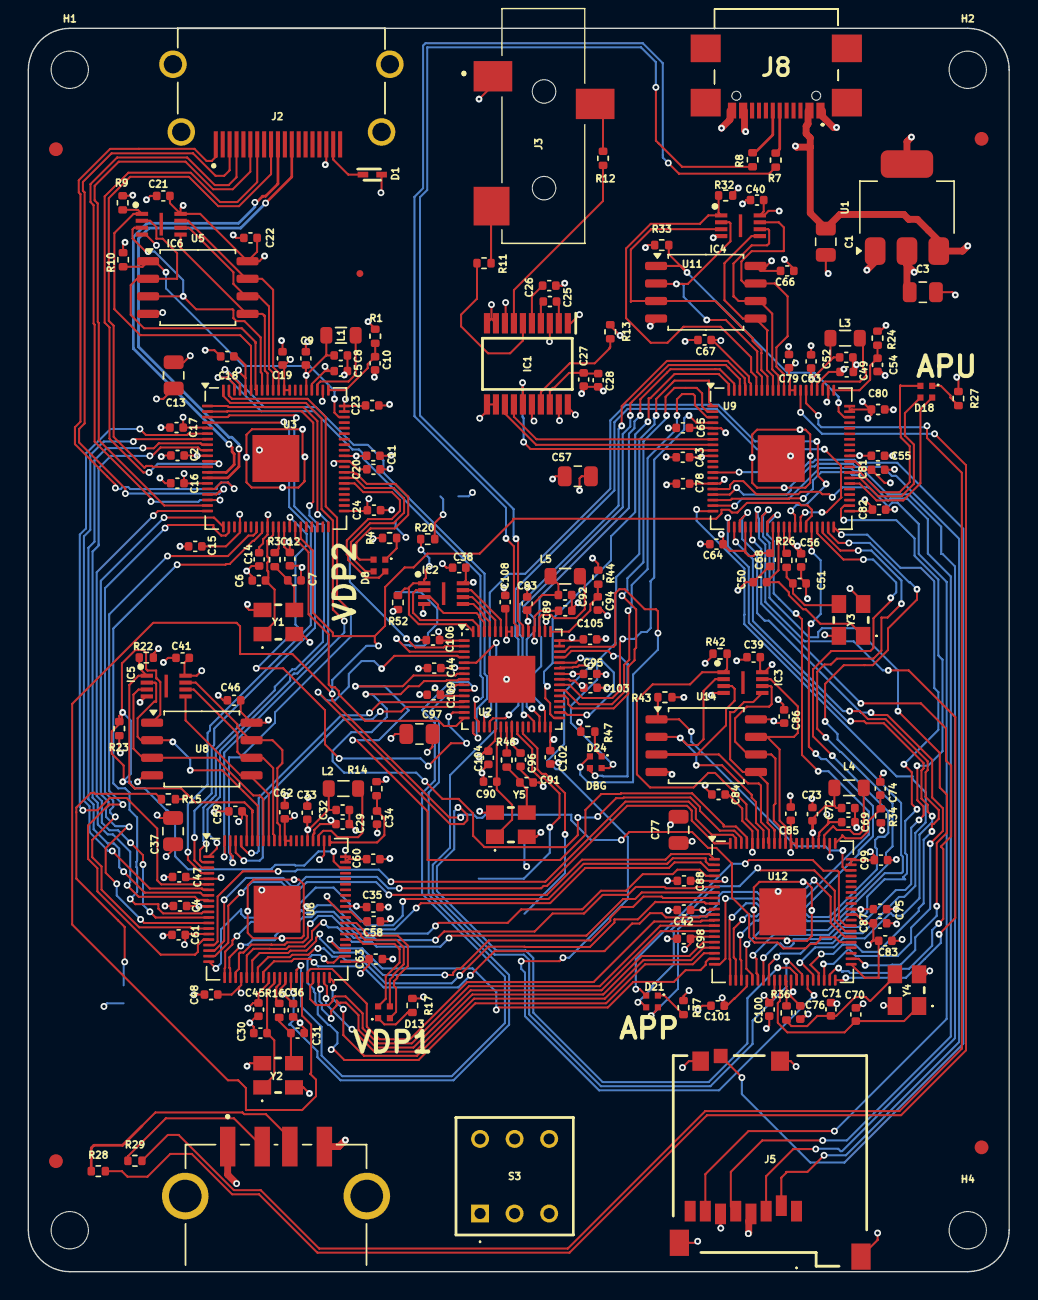
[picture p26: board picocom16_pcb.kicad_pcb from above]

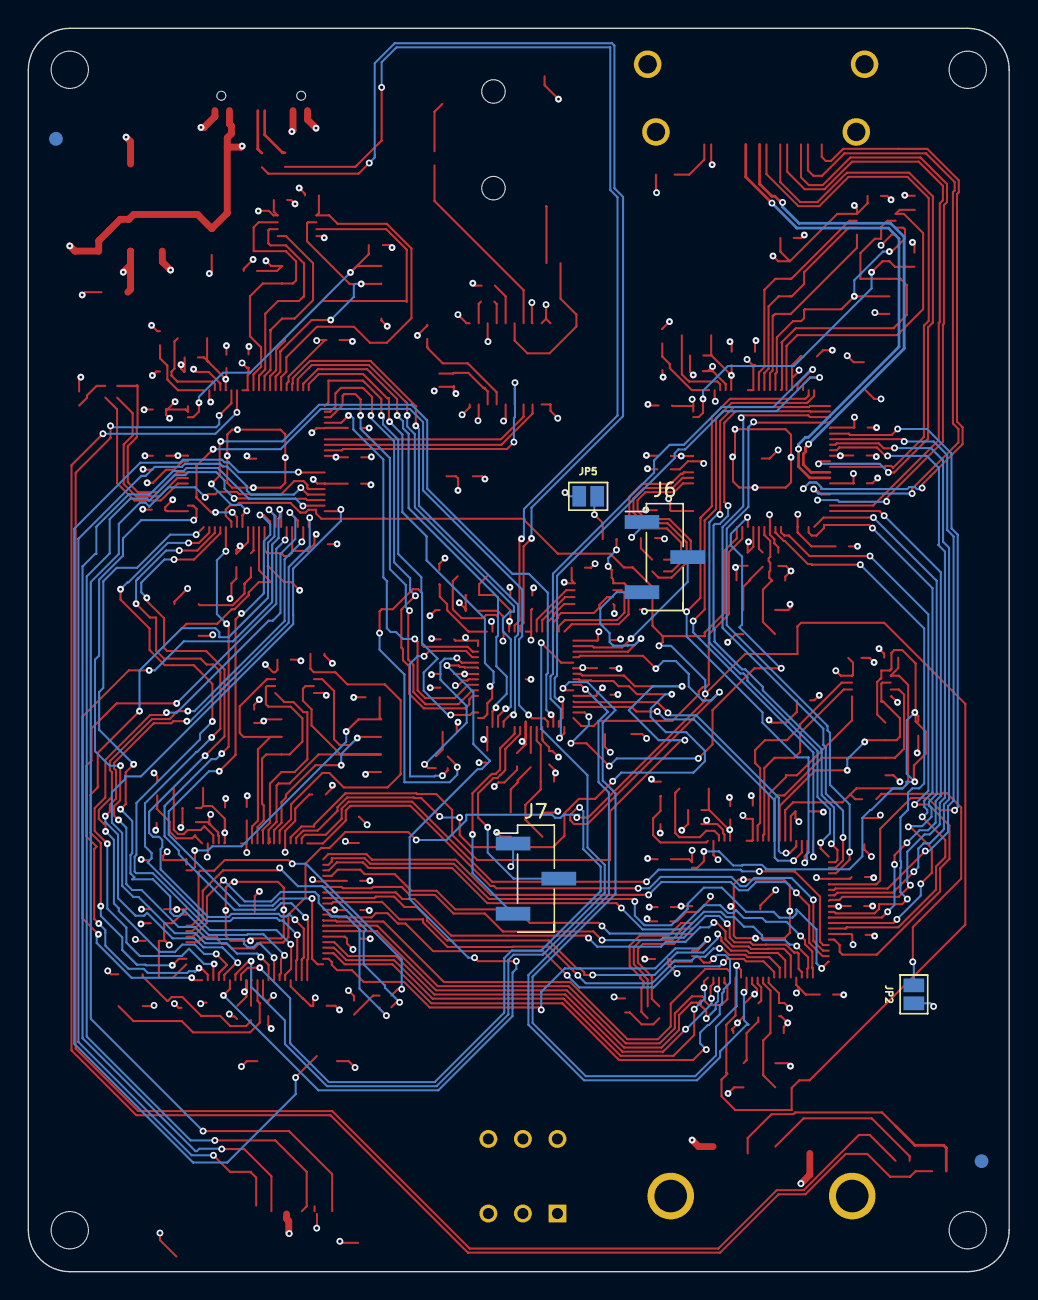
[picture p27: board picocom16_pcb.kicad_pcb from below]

Board: 4 copper layers, 71.0 x 90.0 mm, 194 parts (6 on the bottom side), 195 nets.

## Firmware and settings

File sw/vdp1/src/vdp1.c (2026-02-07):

/** VDP1 GPU
    - processes foreground draw commands (on both cores)
    - DMA writes scanlines to VDP2 for compositing & post processing
*/
/** Simulated vdp2 core
 * - links bus to fake hw 
 * - run vdp2 core with bus & display config
 * - display frame buffer abstracted in display_driver_* lib
 * Note:
 *  - hw main will just pass pio and a similar config
 */
#include "lib/components/vdp1_core/vdp1_core.h"
#include "platform/pico/hw/picocom_hw.h"
#include "platform/pico/hw/picocom_hw.h"
#include "hardware/clocks.h"
#include <string.h>
#include <stdio.h>
#include <hardware/gpio.h>

struct vdp1_t* g_vdp1 = 0;

//
//
void main()
{    
    set_sys_clock_khz(VDP1_CLOCK_KHZ, true);
    sleep_ms(10);

    // Blink led to show active chip when debugging, also give dbg time to setup boot order.
    reset_pico_gpio();
    picocom_hw_init_led_only(true);
    gpio_init(PICO_DEFAULT_LED_PIN);
    gpio_set_dir(PICO_DEFAULT_LED_PIN, GPIO_OUT);    
    gpio_put(PICO_DEFAULT_LED_PIN, 1);
    sleep_ms(100);
    gpio_put(PICO_DEFAULT_LED_PIN, 0);
    sleep_ms(100);
    gpio_put(PICO_DEFAULT_LED_PIN, 1);
        
    stdio_init_all();
    printf("vdp1 init\n");

    // wait for vdp2
    sleep_ms(100);

    struct vdp1MainLoopOptions_t mainOptions;
    struct vdp1InitOptions_t vdpOptions;
    g_vdp1 = (struct vdp1_t*)picocom_malloc(sizeof(struct vdp1_t));
    memset(g_vdp1, 0, sizeof(*g_vdp1));
    memset(&mainOptions, 0, sizeof(mainOptions));
    memset(&vdpOptions, 0, sizeof(vdpOptions));

    // Create bus links
    static BusTx_t vdp2_vdbus_tx;
    static BusRx_t vdp2_xlnk_rx;    
    static BusTx_t app_vlnk_tx;
    static BusRx_t app_vlnk_rx;    
    
    // Init bus
    bus_tx_configure(
         &vdp2_vdbus_tx,
        VDP1_VDBUS_PIO,
        VDP1_VDBUS_SM,
        VDP1_VDBUS_DATA_CNT,
        VDP1_VDBUS_D0_PIN,
        VDP1_VDBUS_ACK_PIN,
        VDP1_VDBUS_IRQ,
        VDP1_VDBUS_DIV
    );
    vdp2_vdbus_tx.name = "(vdp1)vdp2_vdbus_tx";
    vdp2_vdbus_tx.max_tx_size = 32768*2; // 32k max buffer TODO: header const
    vdp2_vdbus_tx.tx_ack_timeout = 750*1000;    // 750ms timeout
    bus_tx_init( &vdp2_vdbus_tx );

    bus_rx_configure(&vdp2_xlnk_rx,
            VDP1_XLNK_PIO,
            VDP1_XLNK_SM,       
            VDP1_XLNK_DATA_CNT,
            VDP1_XLNK_D0_PIN,
            VDP1_XLNK_ACK_PIN
        );    
    vdp2_xlnk_rx.name = "(vdp1)vdp2_xlnk_rx";    
    bus_rx_init(&vdp2_xlnk_rx);    

    bus_rx_configure(&app_vlnk_rx,
            VDP1_VLNK_RX_PIO,
            VDP1_VLNK_RX_SM,       
            VDP1_VLNK_RX_DATA_CNT,
            VDP1_VLNK_RX_D0_PIN,
            VDP1_VLNK_RX_ACK_PIN
        );
    app_vlnk_rx.name = "(vdp1)app_vlnk_rx";
    bus_rx_init(&app_vlnk_rx);
    
    bus_tx_configure(
        &app_vlnk_tx,
        VDP1_VLNK_TX_PIO,
        VDP1_VLNK_TX_SM,
        VDP1_VLNK_TX_DATA_CNT,
        VDP1_VLNK_TX_D0_PIN,
        VDP1_VLNK_TX_ACK_PIN,
        VDP1_VLNK_TX_IRQ,
        VLNK_DIV
    );
    app_vlnk_tx.name = "(vdp1)app_vlnk_tx";    
    app_vlnk_tx.max_tx_size = APP_VLNK_RX_BUFFER_SZ; // Max app rx size ( limited by rx buffer )
    bus_tx_init( &app_vlnk_tx );

    vdpOptions.vdp2_vdbus_tx = &vdp2_vdbus_tx;
    vdpOptions.vdp2_xlnk_rx = &vdp2_xlnk_rx;
    vdpOptions.app_vlnk_tx = &app_vlnk_tx;
    vdpOptions.app_vlnk_rx = &app_vlnk_rx;
    vdpOptions.vdp2CmdFwdWriteBufferSz = 0;
    vdpOptions.gpuOptions.bufferRamSz = VDP1_GPU_RAM_SZ;
    vdpOptions.gpuOptions.enableFlash = true;


    // init vdp core
    int res;
    res = vdp1_init(g_vdp1, &vdpOptions);
    if(res != SDKErr_OK)
    {
        printf("vdp1_init failed %d\n", res);
        return;
    }

    // run main loop
    vdp1_main(g_vdp1, &mainOptions);
}

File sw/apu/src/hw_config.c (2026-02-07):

/* hw_config.c
Copyright 2021 Carl John Kugler III

Licensed under the Apache License, Version 2.0 (the License); you may not use 
this file except in compliance with the License. You may obtain a copy of the 
License at

   http://www.apache.org/licenses/LICENSE-2.0 
Unless required by applicable law or agreed to in writing, software distributed 
under the License is distributed on an AS IS BASIS, WITHOUT WARRANTIES OR 
CONDITIONS OF ANY KIND, either express or implied. See the License for the 
specific language governing permissions and limitations under the License.
*/
/*

This file should be tailored to match the hardware design.

There should be one element of the spi[] array for each hardware SPI used.

There should be one element of the sd_cards[] array for each SD card slot.
The name is should correspond to the FatFs "logical drive" identifier.
(See http://elm-chan.org/fsw/ff/doc/filename.html#vol)
The rest of the constants will depend on the type of
socket, which SPI it is driven by, and how it is wired.


    spi = machine.SPI(1,
                    baudrate=1000000,
                    polarity=0,
                    phase=0,
                    bits=8,
                    firstbit=machine.SPI.MSB,
                    sck=machine.Pin(10),
                    mosi=machine.Pin(11),
                    miso=machine.Pin(8))
    spi.init()  # Ensure right baudrate
    sd = sdcard.SDCard(spi, machine.Pin(9))  # Compatible with PCB


*/

#include <string.h>
#include "my_debug.h"
#include "hw_config.h"
#include "ff.h" /* Obtains integer types */
#include "diskio.h" /* Declarations of disk functions */
#include "platform/pico/hw/picocom_hw.h"

// Hardware Configuration of SPI "objects"
// Note: multiple SD cards can be driven by one SPI if they use different slave
// selects.
static spi_t spis[] = {  // One for each SPI.
    {
        .hw_inst = APU_SDCARD_SPI,  // SPI component
        .miso_gpio = 16, // GPIO number (not pin number)
        .mosi_gpio = 19,
        .sck_gpio = 18,
        .baud_rate = 12500 * 1000,  
        //.baud_rate = 25 * 1000 * 1000, // Actual frequency: 20833333. 
    }
};

// Hardware Configuration of the SD Card "objects"
static sd_card_t sd_cards[] = {  // One for each SD card
    {
        .pcName = "0:",   // Name used to mount device
        .spi = &spis[0],  // Pointer to the SPI driving this card
        .ss_gpio = 17,    // The SPI slave select GPIO for this SD card
        .use_card_detect = true,        
        .card_detect_gpio = 20,   // Card detect (breadboard)
        //.card_detect_gpio = 0,   // Card detect disable
        .card_detected_true = 0  // What the GPIO read returns when a card is
                                    // present. Use -1 if there is no card detect.
    }};

/* ********************************************************************** */
size_t sd_get_num() { return count_of(sd_cards); }
sd_card_t *sd_get_by_num(size_t num) {
    if (num <= sd_get_num()) {
        return &sd_cards[num];
    } else {
        return NULL;
    }
}
size_t spi_get_num() { return count_of(spis); }
spi_t *spi_get_by_num(size_t num) {
    if (num <= sd_get_num()) {
        return &spis[num];
    } else {
        return NULL;
    }
}

/* [] END OF FILE */

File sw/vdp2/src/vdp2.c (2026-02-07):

//#pragma GCC optimize ("O0")
/** vdp2 core
 * - links bus to hw 
 * - run vdp2 core with bus & display config
 * - display frame buffer abstracted in display_driver_* lib
 */
#include "lib/components/vdp2_core/vdp2_core.h"
#include "picocom/display/display.h"
#include "platform/pico/hw/picocom_hw.h"
#include "platform/pico/vdp2/hw_vdp2_types.h"
#include "lib/platform/pico/vdp2/hw_vdp2_types.h"
#ifdef PICOCOM_SDL
#include "lib/platform/sdl2/display/sdl_display_driver.h"
#endif
#include "picocom/devkit.h"
#include <string.h>
#include <stdio.h>
#include "picocom/utils/profiler.h"

void vdp2_testbed();
void dev_test();

struct vdp2_t* g_vdp2 = 0;


//
//
void main()
{
#ifdef VDP2_DEV_TEST
    dev_test();
#endif

#ifdef VDP2_INLINE_OPTIM_TESTBED
    vdp2_testbed();
#endif

    // Blink led to show active chip when debugging, also give dbg time to setup boot order.
    gpio_init(PICO_DEFAULT_LED_PIN);
    gpio_set_dir(PICO_DEFAULT_LED_PIN, GPIO_OUT);    
    gpio_put(PICO_DEFAULT_LED_PIN, 1);
    sleep_ms(100);
    gpio_put(PICO_DEFAULT_LED_PIN, 0);
    sleep_ms(100);
    gpio_put(PICO_DEFAULT_LED_PIN, 1);

    reset_pico_gpio();
    
    // Init driver & clocks
    display_driver_init();
    flip_display_blocking();

    // Init stdio (post)
    stdio_init_all();
    printf("vdp2 init\n");
    
    struct vdp2MainLoopOptions_t mainOptions;
    struct vdp2InitOptions_t vdpOptions;
    g_vdp2 = (struct vdp2_t*)picocom_malloc(sizeof(struct vdp2_t));
    memset(g_vdp2, 0, sizeof(*g_vdp2));
    memset(&mainOptions, 0, sizeof(mainOptions));
    memset(&vdpOptions, 0, sizeof(vdpOptions));

    // Create bus links
    static BusTx_t vdp1_xlnk_tx;
    static BusRx_t vdp1_vdbus_rx;    
    
    bus_rx_configure(&vdp1_vdbus_rx,
            VDP2_VDBUS_PIO,
            VDP2_VDBUS_SM,       
            VDP2_VDBUS_DATA_CNT,
            VDP2_VDBUS_D0_PIN,
            VDP2_VDBUS_ACK_PIN
        );
    vdp1_vdbus_rx.name = "(vdp2)vdp1_vdbus_rx";    
    vdp1_vdbus_rx.rx_buffer_size = MAX(sizeof(struct VDP2CMD_TileFrameBuffer16bpp), 1024); // Alloc room for tile buffer
    bus_rx_init(&vdp1_vdbus_rx);
    
    bus_tx_configure(
        &vdp1_xlnk_tx,
        VDP2_XLNK_PIO,
        VDP2_XLNK_SM,
        VDP2_XLNK_DATA_CNT,
        VDP2_XLNK_D0_PIN,
        VDP2_XLNK_ACK_PIN,
        VDP2_XLNK_IRQ,
        XLNK_DIV
    );
    vdp1_xlnk_tx.name = "(vdp2)vdp1_xlnk_tx";
    bus_tx_init( &vdp1_xlnk_tx );

    vdpOptions.vdp1_xlnk_tx = &vdp1_xlnk_tx;
    vdpOptions.vdp1_vdbus_rx = &vdp1_vdbus_rx;
    vdpOptions.gpuOptions.bufferRamSz = VDP2_GPU_RAM_SZ;
    vdpOptions.initDisplayDriver = 0;

    // init vdp core
    int res;
    res = vdp2_init(g_vdp2, &vdpOptions);
    if(res != SDKErr_OK)
    {
        printf("vdp2_init failed %d\n", res);
        return;
    }

    // run mainloop
    vdp2_main(g_vdp2, &mainOptions);
}

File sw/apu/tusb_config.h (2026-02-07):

/*
 * The MIT License (MIT)
 *
 * Copyright (c) 2019 Ha Thach (tinyusb.org)
 *
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
 */

#ifndef _TUSB_CONFIG_H_
#define _TUSB_CONFIG_H_

#ifdef __cplusplus
 extern "C" {
#endif

//--------------------------------------------------------------------
// Common Configuration
//--------------------------------------------------------------------

// defined by compiler flags for flexibility
#ifndef CFG_TUSB_MCU
#error CFG_TUSB_MCU must be defined
#endif

#ifndef CFG_TUSB_OS
#define CFG_TUSB_OS           OPT_OS_NONE
#endif

#ifndef CFG_TUSB_DEBUG
#define CFG_TUSB_DEBUG        0
#endif

/* USB DMA on some MCUs can only access a specific SRAM region with restriction on alignment.
 * Tinyusb use follows macros to declare transferring memory so that they can be put
 * into those specific section.
 * e.g
 * - CFG_TUSB_MEM SECTION : __attribute__ (( section(".usb_ram") ))
 * - CFG_TUSB_MEM_ALIGN   : __attribute__ ((aligned(4)))
 */
#ifndef CFG_TUH_MEM_SECTION
#define CFG_TUH_MEM_SECTION
#endif

#ifndef CFG_TUH_MEM_ALIGN
#define CFG_TUH_MEM_ALIGN     __attribute__ ((aligned(4)))
#endif

//--------------------------------------------------------------------
// Host Configuration
//--------------------------------------------------------------------

// Enable Host stack
#define CFG_TUH_ENABLED       1

#if CFG_TUSB_MCU == OPT_MCU_RP2040
  // #define CFG_TUH_RPI_PIO_USB   1 // use pio-usb as host controller
  // #define CFG_TUH_MAX3421       1 // use max3421 as host controller

  // host roothub port is 1 if using either pio-usb or max3421
  #if (defined(CFG_TUH_RPI_PIO_USB) && CFG_TUH_RPI_PIO_USB) || (defined(CFG_TUH_MAX3421) && CFG_TUH_MAX3421)
    #define BOARD_TUH_RHPORT      1
  #endif
#endif

// Default is max speed that hardware controller could support with on-chip PHY
#define CFG_TUH_MAX_SPEED     BOARD_TUH_MAX_SPEED

//------------------------- Board Specific --------------------------

// RHPort number used for host can be defined by board.mk, default to port 0
#ifndef BOARD_TUH_RHPORT
#define BOARD_TUH_RHPORT      0
#endif

// RHPort max operational speed can defined by board.mk
#ifndef BOARD_TUH_MAX_SPEED
#define BOARD_TUH_MAX_SPEED   OPT_MODE_DEFAULT_SPEED
#endif

//--------------------------------------------------------------------
// Driver Configuration
//--------------------------------------------------------------------

// Size of buffer to hold descriptors and other data used for enumeration
#define CFG_TUH_ENUMERATION_BUFSIZE 256

#define CFG_TUH_HUB                 1
#define CFG_TUH_CDC                 0
#define CFG_TUH_HID                 (3*CFG_TUH_DEVICE_MAX) // typical keyboard + mouse device can have 3-4 HID interfaces
#define CFG_TUH_MSC                 0
#define CFG_TUH_VENDOR              0

// max device support (excluding hub device): 1 hub typically has 4 ports
#define CFG_TUH_DEVICE_MAX          (3*CFG_TUH_HUB + 1)

//------------- HID -------------//

#define CFG_TUH_HID_EP_BUFSIZE      64

#ifdef __cplusplus
 }
#endif

#endif /* _TUSB_CONFIG_H_ */

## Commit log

2026-02-07 added hw design kicad project files
    [picocom16_app.kicad_sch, picocom16_apu.kicad_sch, picocom16_dbg.kicad_sch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]
2026-02-07 demos added
    [T_Rex_1_FBX_LOW.fbx.obj, cube.obj]
